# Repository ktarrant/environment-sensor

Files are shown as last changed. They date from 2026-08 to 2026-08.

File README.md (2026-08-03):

# environment-sensor
ESPHome device with ESP32 and BME280 to report Temp/Humidity to Home Assistant

Physically it is two enclosures joined by a 4-pin cable: an MCU end and a sensor
end. The circuit boards are built; the enclosures are in design.

## Layout

| | |
| --- | --- |
| [BOM.md](BOM.md) | The exact parts, with what is verified and what is not |
| [docs/assembly.md](docs/assembly.md) | **The wiring**, and the MCU module as built |
| [docs/measuring.md](docs/measuring.md) | How parts were dimensioned without a caliper |
| [docs/enclosure.md](docs/enclosure.md) | **The enclosure plan** - three units, two shells each |
| [hardware/](hardware/) | OpenSCAD models. `params.scad` holds every dimension |
| [reference/](reference/) | Third-party models kept for cross-checking |
| [images/](images/) | Photos the dimensions were measured from, and renders |

## Build

Needs OpenSCAD (2021.01 tested). `make` writes STLs to `build/` and renders to
`images/renders/`.

```
make                    # everything
make assembly           # just the MCU module
OPENSCAD=/path/to/openscad make
```

## Wiring

Components sit on the face opposite the perfboard silkscreen; the wiring runs on
the silkscreen face so the A..N / 1..20 grid stays readable while soldering.

| # | Signal | Connector | ESP32 hole | ESP32 pin | Wire |
| --- | --- | --- | --- | --- | --- |
| 1 | Power  | C20 (pin 1) | L2  | `3V3` | red |
| 2 | Ground | D20 | B3  | `GND` | black |
| 3 | Clock  | E20 | L15 | `GPIO22 (SCL)` | orange |
| 4 | Data | F20 | L12 | `GPIO21 (SDA)` | blue |

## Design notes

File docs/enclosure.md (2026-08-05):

# Enclosure design plan

Three complete units, one per room. Each unit is **two printed enclosures on a
short pigtail**: an MCU box and a sensor pod. The boards are built and will not
be modified, so every dimension here is a consequence of
[`hardware/params.scad`](../hardware/params.scad), not a free choice.

| Unit | Location | MCU box | Sensor pod |
| --- | --- | --- | --- |
| A | Utility room | screwed to the side of a cabinet | hangs below the box on the pigtail |
| B | Sunroom | discreet, sits at the base of the LEGO orchid's pot | styled as a leaf / unbloomed bud |
| C | Living room | freestanding on a bookshelf | short stub arm off the box, front edge |

## The one constraint that drives everything

**The BME280 cannot share air with the WROOM.** A WROOM-32 with Wi-Fi up
self-heats enough to bias temperature by several degrees, and relative humidity
follows the temperature error. That is why there are two enclosures and not one
box with a divider - a divider still shares the wall, and 3D-printed plastic
conducts well enough to matter at these deltas.

Three rules follow, and they are non-negotiable in every variant:

1. **The pod is a separate volume on a pigtail**, 10-20 cm, per the decision
   made for this design.
2. **The pod is never directly above the MCU box.** Warm air off the box rises;
   put the pod level with it or below, and offset laterally. Unit A hangs the
   pod below the box for exactly this reason.
3. **The pod is vented top and bottom** so it convects, and the BME280 can
   itself sits in the airflow rather than behind a wall.

## Architecture: one family, swappable mounts

Do not design three enclosures. Design **one MCU box and one pod**, each with a
mount interface, and make the three locations three small adapter parts.

```
hardware/
  enclosure_common.scad     shell / lid / boss / vent-slot library, no dimensions of its own
  enclosure_mcu.scad        part = "base" | "lid" | "check"
  enclosure_sensor.scad     part = "base" | "lid" | "check";  style = "plain" | "bud"
  mounts.scad               part = "cabinet" | "shelf" | "orchid"
  fitgauge.scad             printed first, before any enclosure
```

The mount interface is a **dovetail or two-screw pad on the MCU box's back
face**, identical across all three, so a unit can be moved between rooms by
reprinting a 5 g adapter instead of the box. Adding this costs almost nothing
now and is very expensive to retrofit.

Every new dimension goes in `params.scad` with a confidence tag, same as
everything else. `enclosure_common.scad` should hardcode nothing.

## MCU box

### The envelope, from the model

`make assembly` echoes these; they are not estimates.

| | |
| --- | --- |
| Board | 60.00 x 40.00, mounted on its four corner holes, **M2 only** |
| Mount pattern | 56.34 x 36.02 |
| Above the wiring face | **13.20** - the mated connector, not the ESP32 |
| ESP32 stack top | 8.84 - 4.4 mm of headroom under the connector's number |
| Below the wiring face | **4.36** - untrimmed ESP32 header tails, plus the wiring itself |
| Total board-to-board | 17.56 |
| USB-C | -X end, stands **3.31 proud** of the board edge, window at Z = 5.74 to 9.00 above the wiring face |
| ESP32 PCB overhang | 1.56 past the -X board edge, under the USB port |

Interior floor-to-lid is therefore **~13.2 + standoff + margin**, and the
standoff must clear 4.36 of pin tails *plus* the wire runs on that face. Start
at **6.0 mm** standoffs and confirm on the real board - the wiring is hand-laid
and nobody has measured how proud it sits.

### The cable exit is the awkward part

The MCU connector is a **straight header on row 20** - the plug pulls
**straight up**, not sideways, and its face is 13.2 mm above the wiring face.
The cable then has to turn 90 degrees to leave the box. It also sits **7.62 mm
off the board centerline** toward column A (columns C..F), so the exit is *not*
on the box's midline. Two options:

- **Side exit at the +X wall** (recommended). Needs the interior to run to
  roughly 13.2 + one cable bend radius above the board, call it 22-24 mm, with
  a slot in the +X wall at the top. Only 5.87 mm separates the connector center
  from the board edge, so the bend is tight - measure the cable's real minimum
  radius before fixing this.
- **Top exit straight through the lid.** Shortest possible box, but the cable
  stands off the lid, which rules it out for the cabinet mount and looks wrong
  in the sunroom.

Whichever is chosen, **allow `xh_solder_tilt` (5 deg)** at the exit and around
the plug. The built connectors are visibly askew; a slot sized for a
perpendicular plug will bench-test fine and then refuse to close.

USB-C exits the **opposite** (-X) wall, so the two openings never interact.
Cut the USB window oversize - `usb_overhang` at 1.75 is flagged in `params.scad`
as the single highest-risk number in the project - and relieve the outside face
so a chunky USB-C overmold can seat.

### Construction

- Tub + lid. Print the tub open-side-up and the lid face-down: no supports
  anywhere, and the only bridge is the top edge of the USB-C window.
- Vent slots in the walls only, vertical, 1.6 mm (4 nozzle widths) so they
  bridge cleanly. The MCU box vents to keep itself cool; it does **not** need
  to be sensor-grade.
- Do not design a snap-fit lid first - snap fits need a tuned clearance, and
  `clearance` is still `[EST]` at 0.20.

### How it fastens: one screw per corner

The obvious scheme - four screws for the board, four more for the lid - does
not fit. The board is 60 x 40 in an interior that is 63.5 x 40.4, and its
corner holes sit ~1.9 mm from the edges, so the four corners are the *only*
place a post can stand and the board is already using them. Widening the box
to make room for separate lid posts costs ~10 mm across.

So one screw does three jobs:

```
   M2 x 16, head counterbored into the OUTSIDE of the floor
     |  up through the standoff tube        (clearance)
     |  through the perfboard's corner hole (2.2 mm, clearance)
     +->into a post hanging off the lid     (tapped, 6 mm engagement)
```

The board is trapped between the standoff below and the lid post above, and is
**located by the screw shanks** through its 2.2 mm corner holes - not by the
posts, which carry a 2.4 mm clearance bore and so cannot also spigot into a
2.2 mm hole. Nothing else locates it: the cavity walls are deliberately loose
(`enc_board_gap`, 0.4 a side) because a tight cavity would only make the board
hard to drop in without holding it any better.

The heads end up on the outside of the floor, which is where a mount adapter
gets captured later without adding fasteners - at the cost of ~2 mm more screw
length per adapter.

Two consequences:

- The screws are on the bottom, so a wall-mounted unit comes off its keyholes
  before it can be opened. For a sensor that is opened once a year, that is the
  right trade.
- `enc_post_od` is **not a free choice**. At the -X/+Y corner the ESP32's own
  PCB edge is 2.49 mm from the screw axis, so the post is 4.20 mm and clears
  the board it is holding down by **0.39 mm**. Widening it collides. There is
  an `assert()` on exactly this.

## Sensor pod

The board is 13 x 10 and ~2.5 thick, and it is not what sets the size. The
**connector straddles the board** - mated plug 11.6 mm off the trace side,
components and pin tails 3.4 on the other - and the plug's housing is 12.52 mm
wide against a 10 mm board. The pod comes out **27.8 x 21.6 x 21.4** and every
millimetre of that is the connector.

`hardware/enclosure_sensor.scad`, two clamshell halves, built and manifold with
an empty check. Not printed.

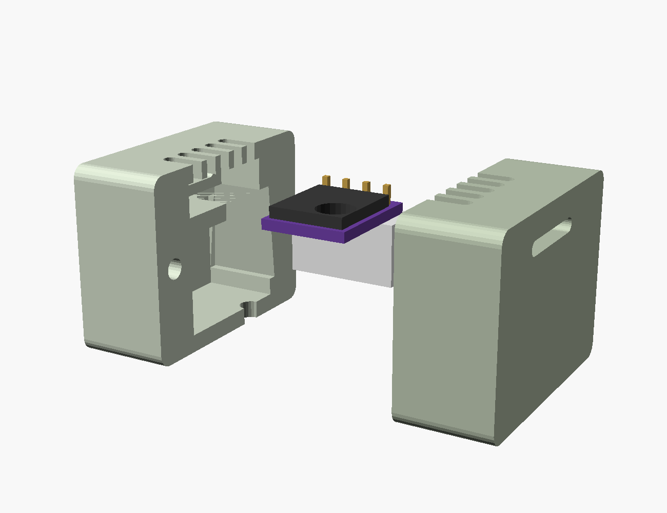
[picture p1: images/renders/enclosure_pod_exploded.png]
pod


### Why a clamshell and not a tub and lid

The interconnect has a housing on **both** ends - both boards carry male
headers - so the cable cannot be threaded through a closed hole, and a hole big
enough to pass a plug is most of the pod's end face. The exit therefore has to
be split between the two halves, which puts the parting plane through the cable
axis. That decision then pays for itself twice over: the halves close sideways
onto the board, so nothing has to be inserted along Z, and the cable gland is
just a half-round in each half that clamps the cable when the screws go in.

### The board is held by the connector, not by a screw

The board's single mounting hole is `[EST]` and its Y sign is
**mirror-ambiguous** - read off a bottom-side photo, so a boss built on it
could land 4 mm out on a 10 mm board. Nothing in this pod uses it, and nothing
here is blocked on that photo.

The connector does the work instead, because it is soldered to the board and
its top face is flush with the board's underside at Z = 0:

- **above Z = 0** the cavity is the *board's* outline only, so shell material
  stands over the connector's flange - it overhangs the board by 1.26 mm each
  side and 0.85 mm past the end - and stops the assembly lifting;
- **below Z = 0** the cavity is the *connector's* outline only, so shell
  material remains under the board out to x = 1.10 and holds it up.

Two boxes, and the board is located in X, Y, Z and rotation with no fastener
through it. It only works because the halves close laterally - a tub and lid
would need insertion clearance in Z and would lose the shoulder. Three
`assert()`s guard it; if any fails the board is loose and the render still
looks perfect.

### The plug pocket leans

`xh_solder_tilt` is finally load-bearing rather than a note. The pocket tapers
**2.03 mm** wider over the plug's depth, so a connector soldered up to 5 degrees
off square still seats. A pocket cut for a perpendicular plug is the classic
way to end up with a pod that will not close, and this one is deep enough
(11.6 mm) for 5 degrees to matter. The taper leans toward the +X screw as it
deepens; there is 1.26 mm left between them, and an assert that says so.

### Venting

- A **grille of 5 slots directly over the sensor**, 48% open, with 2 mm of wall
  between it and the BME280's can.
- One **cross-flow slot** through both side walls, level with the can, so air
  crosses the chamber instead of sitting in it.

### Printing, and the taper that had to go

Each half prints on its **outer face, opening up**. In that orientation every
internal surface is either vertical or a floor with solid material beneath it -
the chamber, the plug pocket and the lower chamber all open upward, the screw
holes run straight up the build direction, and the cable gland is a groove in
the top face. No supports, no bridges.

Getting there cost the pod its taper. The shell used to be narrow over the
sensor and full width over the plug, which thinned the chamber's side walls to
2 mm. The slicer rejected it, and it was right twice over:

- **A clamshell half is a bowl.** Printed rim-down - which is what "on its
  parting face" meant, and it is self-contradictory with "opening up" - its own
  outer wall roofs the cavity as an unsupported ceiling. It has to go outer face
  down. That needs the outer face to be **flat**, and a tapered face is not.
- The taper itself ran at **66 degrees off vertical** in that orientation. An
  earlier note here claimed 25 degrees; that was the same arithmetic with rise
  and run swapped.

The corner rounding was reoriented for the same reason - the rounded edges now
run along the build direction instead of putting a 1.5 mm fillet on the face
that sits on the bed.

The cost is real and worth stating: the chamber's side walls are **5.4 mm
instead of 2.0**, so the cross-flow vent is a duct rather than a slot. The
grille still sits 2 mm off the sensor and is 47% open, and it is the main path.
If the pod lags room air on the bench, enlarge the cross-flow cut before
touching anything else.

The MCU box was checked against the same mistake and is fine: its tub prints
open-side-up and its lid plate-down, both with the cavity opening away from the
bed. The only bridge in the project is the top edge of the USB-C window.

### Still to come for the sunroom

Unit B wants a **double-wall shell** over this one - an outer decorative skin
with an air gap - because sun on a pod reads as a temperature spike that has
nothing to do with the room. That is a miniature Stevenson screen wearing a
flower costume, it wraps the pod rather than replacing it, and it is M5.

## The three variants

### A - utility room, cabinet side

MCU box gets a **flanged back with two keyhole slots** so it drops onto two
pan-head screws already in the cabinet side, then a third screw locks it. Box
vertical, USB-C down so the power lead falls naturally and dust does not settle
in the port. Pod hangs **below** on the pigtail in a plain vented shell, either
free on the cable or clipped to a small bracket 10-15 cm down.

### B - sunroom, LEGO orchid

Two parts, deliberately different in character:

- **MCU box**: low and flat, sitting at the base of the pot, in a colour that
  disappears against it. No LEGO geometry - the orchid model does not offer a
  good attachment, so the box just sits. Cable exits toward the plant.
- **Sensor pod as a leaf or unbloomed bud**: an organic outer shell whose seams
  *are* the vents - louvres reading as leaf veins, or a bud whose petal gaps are
  the airflow path. It hangs or perches among the real LEGO leaves at pot
  height, which is also the height worth measuring in that room.

Print unit B in **PETG, not PLA**. A sunroom behind glass gets near PLA's glass
transition, and a drooping enclosure in a plant is a hard failure to diagnose.

This variant needs the orchid photographed with a scale reference before its
shell is drawn - see below.

### C - living room, bookshelf

Freestanding, so the box carries its own **foot**: stand it on a long edge with
a weighted or wide base so it reads as an object rather than a naked box.
Book-adjacent proportions hide it best. The pod goes on a **short stub arm** off
the front edge so it sits out past the shelf lip and out of the box's thermal
plume, rather than dangling.

## Verifying fit before printing

Two mechanisms, both cheap:

1. **`part = "check"`** in each enclosure file: `intersection()` of the shell
   with the assembly's keepout solids (`esp32_keepout()`,
   `perfboard_keepout()`, `xh_mated_keepout()`). A correct design renders
   **empty**. Anything visible is a collision, found in seconds instead of in
   PLA. This is the natural extension of the `assert()` discipline already in
   the models - asserts catch numbers, this catches geometry.
2. **The fit gauge, printed first** - `hardware/fitgauge.scad`, an 86 x 46 x 3
   plate, `make fitgauge`. It is the idea from the last section of
   [measuring.md](measuring.md), built around the four numbers still guessed:

   | row | what it settles |
   | --- | --- |
   | 5 posts, pilots 1.50-1.90 | `m2_pilot`. Every fastener in the build taps into printed plastic, and this varies by printer and material more than anything else here. Tested at the real 4.2 mm post diameter, where the plastic can actually split |
   | 9 holes, 2.0-3.6 | `cable_od`. The smallest hole the cable passes through **is** its diameter - a measurement, not an estimate, and no caliper needed |
   | 5 windows, -0.30 to +0.30 | the USB-C opening and its overmold relief, in a band milled down to the real 2.0 mm wall |
   | 1 notch with pinch ribs | whether the cable actually snaps into the MCU box's exit and stays there |

   Everything is labelled in hundredths of a millimetre, so "170" is a 1.70 mm
   pilot and "-15" a window 0.15 under nominal. Print it in the material and
   nozzle the enclosures will use - the numbers are only valid for the machine
   that made them.

   Note what is **not** on it: a board-seat pocket. `measuring.md` called for
   one, but neither enclosure locates a board against a cavity wall, so the fit
   it would measure does not exist any more. `enc_board_gap` is 0.4 a side and
   the question is closed.

## Measurements still needed

In priority order. Item 1 blocks printing; 2 blocks unit B's shell only.

1. **The mated plug and its cable**: plug body width and depth, cable outer
   diameter, and how tightly it will actually bend. There is no measured number
   for any of it, and it now sets three things - the MCU box's interior height,
   its cable exit, and the pod's gland, which clamps the cable directly and is
   the one feature that fails outright if `cable_od` is wrong.
2. **The LEGO orchid**, photographed with a 2x4 brick (31.8 mm) in frame:
   pot dimensions, leaf scale, and where a pod could plausibly perch.
3. **The cabinet side** - can it be drilled, or does unit A need adhesive
   mounting instead? Different back geometry either way.
4. **M2 hardware on hand**: every fastener in the project is now an **M2 x 16**,
   four in the MCU box and two in the pod. Confirm that length is available
   before printing anything.

**No longer blocking:** a flat photo of the sensor board was going to be needed
before the pod could be designed, because the mounting hole is `[EST]` and
mirror-ambiguous. The pod does not use that hole, so the photo is now only
worth taking to firm up `bme_pcb_thick` and the outline - neither of which the
design is sensitive to.

## Order of work

| | |
| --- | --- |
| M0 | Take photos 1-3; add the enclosure block to `params.scad`, tagged. **Params done; photos outstanding** |
| M1 | Print the fit gauge (`hardware/fitgauge.scad`, **written**); feed back `m2_pilot`, `cable_od`, `usb_cut_margin` |
| M2 | MCU box v1, plain, no mount. **Drafted - see below.** Fit the real board; iterate the cable exit |
| M3 | Sensor pod, plain vented. **Drafted.** Fit the real sensor board |
| M4 | Three mount adapters; print unit A and unit C |
| M5 | The bud/leaf shell for unit B, in PETG |
| M6 | ESPHome config, then check all three against one reference thermometer in one room before they are dispersed |

M6 is not optional. Three sensors that disagree by a degree are three sensors
you cannot trust; measure the offsets while they are still on the same table.

## The MCU box as drafted

`hardware/enclosure_mcu.scad`, built and manifold, collision check empty. Not
printed yet - every number below is a model, not a measurement.

| | |
| --- | --- |
| Exterior | **67.9 x 44.8 x 27.6 mm** |
| Interior | 63.9 x 40.8 x 23.2 |
| Board sits | 6.0 mm above the inner floor, 17.2 below the rim |
| Fasteners | 4x **M2 x 16**, from below |
| Lid post clearance to the ESP32 | 0.39 mm |
| USB-C shell face | 0.65 mm inside the outer wall - hence the relief pocket |

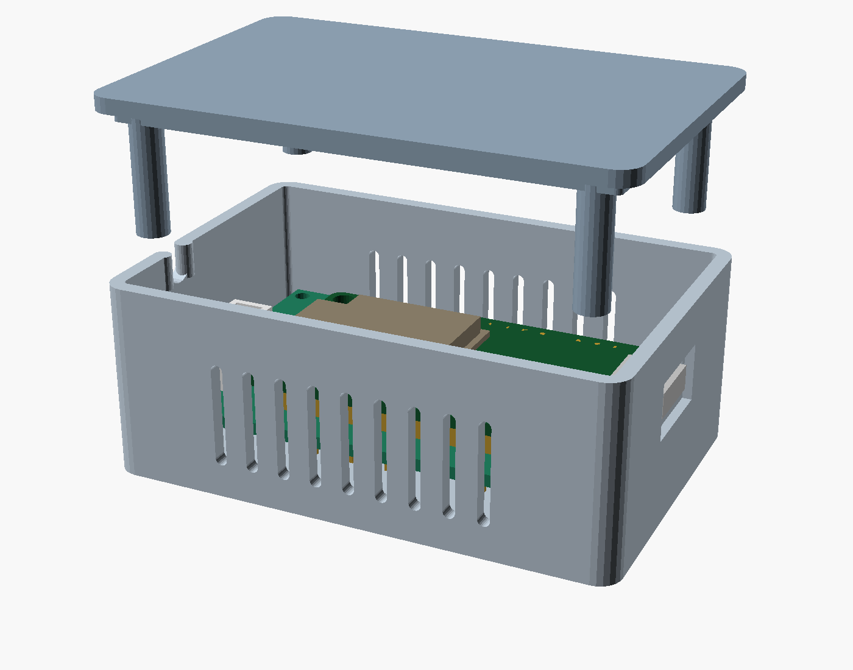
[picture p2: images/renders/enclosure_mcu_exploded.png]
exploded


Two details in the render that look like mistakes and are not: the cable exit
is off the box's midline, because the connector sits on columns C..F rather
than centered; and the box is much deeper above the board than below, because
the mated plug is 13.2 mm tall while the ESP32 stack is only 8.84.

### Still soft in this draft

- `enc_standoff_h = 6.00` clears the 4.36 mm of header tails, but the
  hand-laid wiring on that face has never been measured. First thing to raise
  if the board will not sit flat.
- `enc_cable_head = 4.00` is a stand-in for a bend radius nobody has measured.
- `usb_plug_w/h` - the relief pocket is sized for a guess at the overmold.
- All three belong on the fit gauge.

## What `make check` is and is not good for

It intersects each enclosure with the hardware keepouts and must print
`Current top level object is empty`. Both do. It has now been run in anger on
both ends, and the record is worth keeping honestly:

**What it caught.** Nothing structural in the MCU box - but writing it forced a
correction. The first run reported eight collisions, all of them standoff tops
and post bottoms, i.e. the surfaces that are *supposed* to touch the board. A
keepout that forbids the clamping scheme reports the design as broken by design,
so both checks now exempt exactly the intended bearing surfaces and nothing
else: a ring at each corner hole in the box, the Z = 0 plane in the pod.

At the sensor end it caught a real error, though in the keepout rather than the
pod: `sensor_keepout()` padded the connector's pin tails out by a whole pitch,
making them 10.56 mm wide on a **10 mm board** - impossible, and it would have
flagged any pod built correctly to the board. Sized from the pin row itself now.

**What it missed.** Three real defects, all found by rendering the part and
looking at it:

1. The MCU cable exit was cut to the same height in the lid as in the tub, so
   the channel was open at the top and the cable would lift straight out.
2. The strain-relief ribs sat inside the `difference()`, so the notch erased the
   very bumps meant to pinch the cable.
3. The pod's cross-flow slot originally ran into the chamber ceiling, leaving a
   zero-thickness sliver.

None is a clearance violation, so no keepout could have found any of them. The
check proves parts do not interpenetrate. It says nothing about whether they do
their job.

**One quirk worth knowing.** When a cavity is the board plus *exactly*
`clearance`, every cavity wall is coplanar with a keepout face and CGAL returns
a zero-facet artifact rather than an empty set - which at a glance is
indistinguishable from a real hit. Both enclosures hit this. The right fix
turned out not to be a fudge factor in the check but `enc_board_gap`: the
cavities are now 0.4 a side because **nothing in either enclosure is located by
a cavity wall** - the MCU board by its screws, the sensor board by its
connector - so a tight cavity was only ever going to make a board hard to drop
in. The coplanarity went away as a side effect.

## What the fit gauge returned

First print. Three rows answered, one failed.

| row | result | change |
| --- | --- | --- |
| cable holes | passes 3.40, not 3.20 | `cable_od` **3.00 -> 3.40**. The pigtail is fatter than assumed |
| USB windows | the **smallest** (-0.30) takes the receptacle and the plug with margin | `usb_cut_margin` **0.80 -> 0.50**. `usb_overhang` and the overmold relief are vindicated - that was the flagged risk and it was fine |
| exit notch | the cable slides through the pinch ribs **without being held** | ribs deleted; see below |
| M2 posts | 1.80 split the post, 1.90 accepted the screw | **unresolved** - see below |

### The strain relief did not work

Two bumps the cable was meant to snap past held nothing. That is worse than
having none: it looks like strain relief, and the load goes into the plug.

The MCU box now uses the pod's approach - a **tongue on the lid** that descends
into the notch and squeezes the cable against the notch floor as the four lid
screws come up. Steel pulling plastic onto the cable, not a press fit. The
interference is now `cable_grip = 0.80` in both enclosures, up from 0.40, since
0.40 is precisely the value that was shown not to grip.

### The post row failed rather than answering

An M2's major diameter is 2.00, so a **1.90 pilot leaves 0.05 mm of radial
thread**. It accepted the screw because it is very nearly a clearance hole, and
it will strip on the first or second assembly. It must not be adopted.

The real finding is that the row **conflated two variables**: pilot diameter and
the strength of a thin free-standing column. It can say "a 4.2 mm post will not
take an M2 thread on this printer"; it cannot say what pilot to use in solid
material. That matters because the two threaded joints in this project are not
alike:

- the **pod's** screws tap into **6 mm-thick solid end walls** - no thin wall to
  split, and not the case that failed;
- the **MCU lid's** posts are exactly the case that failed, and the post
  diameter is capped at 4.58 by the ESP32's PCB edge at one corner, so it cannot
  simply be fattened.

**The break settles it: the post sheared off at the plate, hole intact.** That
is a cantilever failing at its root under driver torque - not the thread
splitting the wall. So the pilot is probably not the problem; the gauge drew the
worst possible version of the joint. A 4.20 column meeting a flat face at a
sharp 90 degrees is a stress riser, and in FDM that junction is a joint in the
weakest direction. Two consequences:

- **`enc_fillet = 1.20`** - every post and standoff in both enclosures now
  flares where it meets the plate it stands on. Free to print (the cone is
  wider at the bottom, so it never overhangs) and it is the actual fix for the
  failure that occurred. On the lid posts the flare is 6.6 across, well over
  the 4.58 the tight corner allows, so an assert holds it high above the board.
- **`make fitgauge` now also builds `fitgauge_screws.stl`** - `part="screws"`,
  a 66 x 58 plate. Three rows:

  | row | what it settles |
  | --- | --- |
  | 5 filleted 4.20 posts | the MCU lid's joint, with the fix applied |
  | the same 5 pilots in a solid 8 mm block | the pod's end walls - no column to shear, no thin wall to split. A different joint that the first gauge never tested separately |
  | 4 plug slots, +0 to +1.50 | **the mated plug's outline.** `connector.scad` assumes the plug's footprint matches the header it pushes onto. Nobody has measured it, and the pod's whole pocket is built on that assumption. The smallest slot the plug passes gives the real outline, and the gap from the modelled 12.52 x 5.75 is the `pod_gap` the pocket actually needs |

  One variable per row instead of one row confounding two. Print this before
  either enclosure.

If the filleted posts still shear, the fallback is to move the thread out of the
lid entirely and into a fat, floor-braced boss in the tub, which reverses the
screw direction and puts the heads on the lid.

## What the second gauge returned

### The printer prints small holes undersize

Both gauges picked **1.90** as the best pilot, in a filleted post and in solid
material alike. At face value that is absurd - an M2's major diameter is 2.00,
so a real 1.90 hole leaves 0.05 mm of thread. The consistent reading is that
this printer takes roughly **0.2 mm off a small hole**, so a modelled 1.90 comes
out near 1.70, which is exactly the textbook M2 pilot. It also explains the
first gauge retrospectively: a modelled 1.80 came out near 1.60, which is a lot
of interference, and the post duly split.

`m2_pilot = 1.90` is therefore a **modelled** number carrying a printer
compensation, and it is the only such number in `params.scad`. On a machine that
holds hole size it goes back to ~1.70.

`cable_od` is deliberately **not** corrected the same way, and the distinction is
worth keeping straight:

> A printed feature measured against another printed feature cancels the
> printer's offset. A printed feature measured against a **real object** does
> not. The screw is not printed, so the pilot needs compensating; the gland is
> printed and is derived from a printed hole, so correcting `cable_od` would
> double-count and make the gland too tight by exactly that amount.

### The plug is a centimetre-class error, not a tenth

The slot row was added on a hunch that `connector.scad`'s assumption - that the
mated plug's footprint matches the header it pushes onto - had never been
checked. It was wrong, and not marginally:

| | modelled | measured |
| --- | --- | --- |
| plug outline | 12.52 x 5.75 (the header's) | **14.52 x 7.75** - passes that slot, not 13.52 x 6.75 |

About **1 mm per side bigger** than assumed. `xh_plug_len` / `xh_plug_depth` are
now real parameters, `xh_mated_keepout()` uses them instead of the header's
outline, and the pod's pocket is derived from the plug rather than the header.

The pod grows from 26.8 x 19.6 to **27.8 x 21.6 x 21.4**. Had this gone
undetected, the pod would have printed, looked perfect, passed its collision
check - which was built on the same wrong assumption - and then refused to close
on the one part it exists to hold. The MCU box absorbed the change without
complaint; it had the room.

## What the first printed pod returned

The cable exit was wrong, and wrong in a way none of the modelling caught
because it was built on the wrong mental picture of the part.

`cable_od = 3.40` came from pushing the interconnect through the gauge's hole
row, and that is a fine measurement of a **bundle**. But at the sensor end there
is no bundle: four wires leave the plug spread across the **7.62 mm pin row**,
and the pod asked them to gather into a single 2.6 mm bore within
`pod_cable_room = 2.00` mm. That is a 60 degree convergence, in the 2 mm nearest
a connector, and no wire with any stiffness in it will do that neatly. The bore
also printed slightly flattened, which turned "barely" into "no".

Two changes:

- **`pod_cable_room` 2.00 -> 4.00**, so there is length in which to gather.
- The exit is a **slot, 7.00 x 3.00**, not a bore - and the 7.00 runs **along Y,
  across the parting plane**, so each half's notch goes deeper rather than the
  pair of them running longer along the seam.

That axis took two goes to get right. The first attempt widened the slot **along
the seam**, which is the one direction the wires were never going to use: the
pin row runs along Y, the parting plane bisects it, and the wires fan out two to
a half *perpendicular* to the seam. Widening along X gave them room they did not
want and left the direction they did want at 2.6 mm.

**The exit no longer clamps, and that is the trade.** Y is both the direction the
wires occupy and the direction the halves close on, so an opening wide enough for
them cannot also squeeze them. What keeps a pull off the solder joints is the
plug, at 14.52 across, being far too big to follow the wires through a 7.00
slot - so a hard tug unmates a latched connector rather than lifting a pad.

The pod grows to **27.8 x 21.6 x 23.4**. An `assert()` now ties
`pod_cable_room` to how far the wires actually have to travel, and another
checks the plug cannot pass the slot.

### Third pod: it fits

Closed by hand on the real board and cable. Screws not yet in hand, so this is a
fit result and not yet an assembly result - but a hand-close already retires the
things that would have forced a params change:

- the **plug pocket** takes the mated plug at the corrected 14.52 x 7.75;
- the **parting faces meet** with the board and cable inside, which means
  nothing in the cavity is proud;
- the **cable exit** passes the four wires on the axis they actually run;
- and by implication `bme_conn_inset` (1.50, `[EST]`) leaves enough connector
  flange for the shoulder, since a wrong value there shows up as either a
  rattling board or halves that will not close.

**Screws in, and it holds. The sensor pod is validated.** Every `[EST]` it
depended on has now survived contact with the real parts: the connector-flange
retention, the plug pocket at the corrected outline, the wire-axis exit slot,
and `m2_pilot = 1.90` in a real tapped joint rather than a gauge.

One thing that result does **not** transfer: the pod taps into 6 mm of solid end
wall. The MCU lid's posts are 4.20 mm columns - the same geometry that sheared
on the first gauge. Same pilot, different joint, and `enc_fillet` is a fix that
has still never been driven.

### The same fact at the MCU end

The wires fan across the pin row there too - the connector sits on columns
C..F - and that notch was 5.00 wide against a 7.62 span. Widened to **8.00**,
and the notch floor changed from a half-round to **flat with radiused corners**:
at 8 mm wide a half-round floor curves up steeply at its edges, and it is the
outermost two wires that would have been crushed between that curve and the
clamp tongue.

The MCU end gets to have it both ways, which the pod does not: the wires fan
along Y and the lid's tongue clamps along Z, so widening one costs nothing in
the other.

## Risks

- **Cable bend radius is unmeasured** and sets the MCU box height. The side-exit
  design falls back to the top exit if the cable turns out to be stiff. A 3.40
  cable is stiffer than the 3.00 assumed.
- **`m2_pilot` is `[OPEN]`** - see above. Nothing should be printed for final
  assembly until it is settled.
- **The pod's retention depends on `bme_conn_inset` (1.50, `[EST]`)**, which
  sets how far the connector overhangs the board and therefore how much flange
  the shoulder has to bear on. At 1.06 mm a side there is room to be wrong, but
  not much.
- **Thermal validation is empirical.** The vent design is a reasoned guess. M6
  is what tells you whether the pod actually reads room air, and the fix if it
  does not is a longer pigtail, which is why the connector is there.

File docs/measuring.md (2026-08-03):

# Measuring the boards without calipers

We have no caliper, and a tape measure is worth about ±1 mm — not enough for an
enclosure with a USB-C cutout. Fortunately we don't need one.

## The trick: the header pitch is the ruler

Both boards use **2.54 mm (0.100") header pitch**. That tolerance is held by the
connector manufacturer to well under 0.1 mm, and there are 18 gaps of it across
the ESP32. So instead of measuring the board, we *count pins* and multiply, then
use the same pitch as the scale reference for everything else.

This makes the measurement self-calibrating: any error in camera distance, lens
distortion, or scanner DPI cancels out, because the reference and the subject are
in the same image at the same scale.

## Procedure

1. Lay the board **flat, component side up**, on a plain sheet of white paper.
   Graph paper is a nice sanity check but is not the reference — the pins are.
2. Shoot **straight down**, phone as far back as focus allows, then crop in.
   Distance reduces perspective error; a close-up wide-angle shot will bow the
   edges outward and inflate every dimension.
3. Diffuse light, no flash. A hard shadow along one edge reads as extra board.
4. Take a second shot of the board **on its side**, so the USB-C connector's
   height and how far it overhangs the PCB edge are both visible in profile.
   This is the shot that determines whether the port cutout works.

Four images total: ESP32 top, ESP32 profile, BME280 top, BME280 profile.

A flatbed scanner at 600 dpi beats all of this if one is available — put the board
face down on the glass, leave the lid open, and scan. That is caliper-grade.

## What comes out of it

Derived from pin count alone, no measurement needed:

| Quantity | Derivation | Value |
| --- | --- | --- |
| ESP32 outer pin centers, along length | 14 gaps x 2.54 | **35.56 mm** |
| BME280 header span | depends on pin count, see BOM.md | 5 gaps x 2.54 = 12.7 mm |

This is also how the ESP32 was *identified*: counting 15 pins per row, not 19,
established that it is a 30-pin DevKit V1 rather than the 38-pin board the BOM
originally assumed. The silkscreen label sequence confirmed it independently.

Read off the images, scaled against the pitch:

- PCB length and width, and the pin inset from each edge
- PCB thickness (profile shot; expect ~1.6 mm, the near-universal standard)
- USB-C shell width, height, overhang past the PCB edge, and its offset from the
  board centerline
- Tallest component and its clearance above the PCB (the WROOM-32 can, and the
  electrolytic cap if present)
- BME280: **pin count** — 4 vs 6 tells us which variant shipped, which we still
  need to confirm. See BOM.md.

## What this produced for the ESP32

Worked end to end on images/ESP32_top.jpg. The pitch fit landed on all 30 pins,
giving a scale of **8.66 px/mm** and a board rotation of only 0.17 deg. Measured
outline: 51.4 +/- 0.9 x 28.7 +/- 0.4 mm, which agreed with the DevKit V1 3MF's
51.50 x 28.50 and so validated that model for the rest of the geometry.

Two cautions learned in the process:

- **The vertical axis reads ~1% high.** The board sat left of and below the
  frame center, so it is viewed slightly obliquely and the horizontal pitch
  reference does not transfer cleanly to the vertical. Board width and header
  row spacing both came out high by about that much. Center the part in frame
  next time, or scan it.
- **A downloaded model is not evidence.** The 3MF is excellent in plan but
  flattened in height, and its USB-C overhang (0.70 mm) disagrees with the photo
  (1.75 mm). Where the two conflict on something the enclosure touches, the
  photo of the actual part wins.

## Closing the loop on the first print

Even with good numbers, print a **fit gauge** before printing the enclosure: a
thin plate carrying the USB-C cutout and the board-seat pocket at several
tolerance offsets (-0.3, -0.15, 0, +0.15, +0.3 mm). It takes a few minutes to
print, and it converts a wrong number into a known number by finding which slot
actually fits. That measured offset then feeds back into `params.scad` as the
printer's real-world clearance, and every later part inherits it.

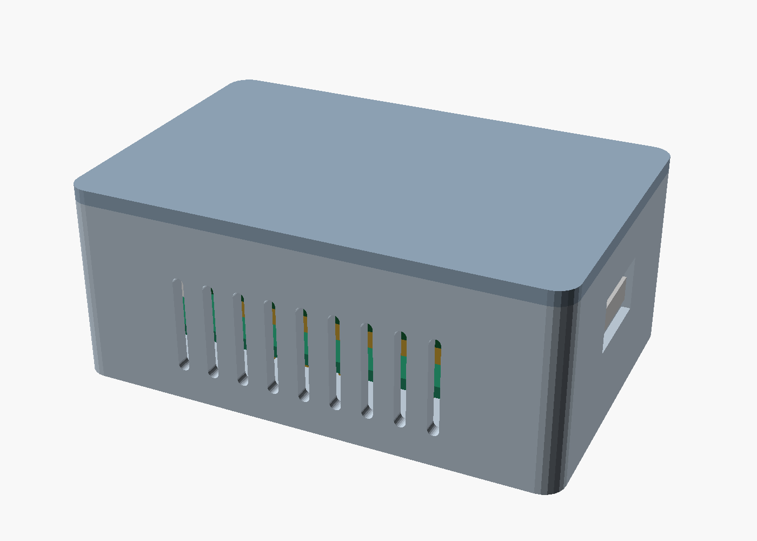
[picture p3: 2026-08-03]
images/renders/enclosure_mcu_iso.png

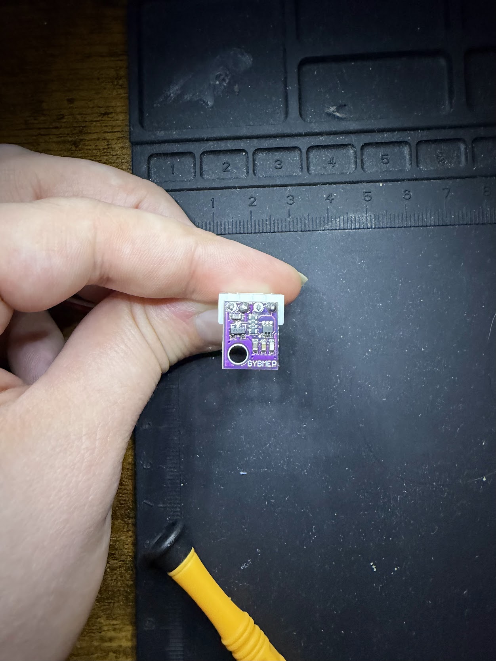
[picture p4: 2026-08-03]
images/sensor_bottom.jpg

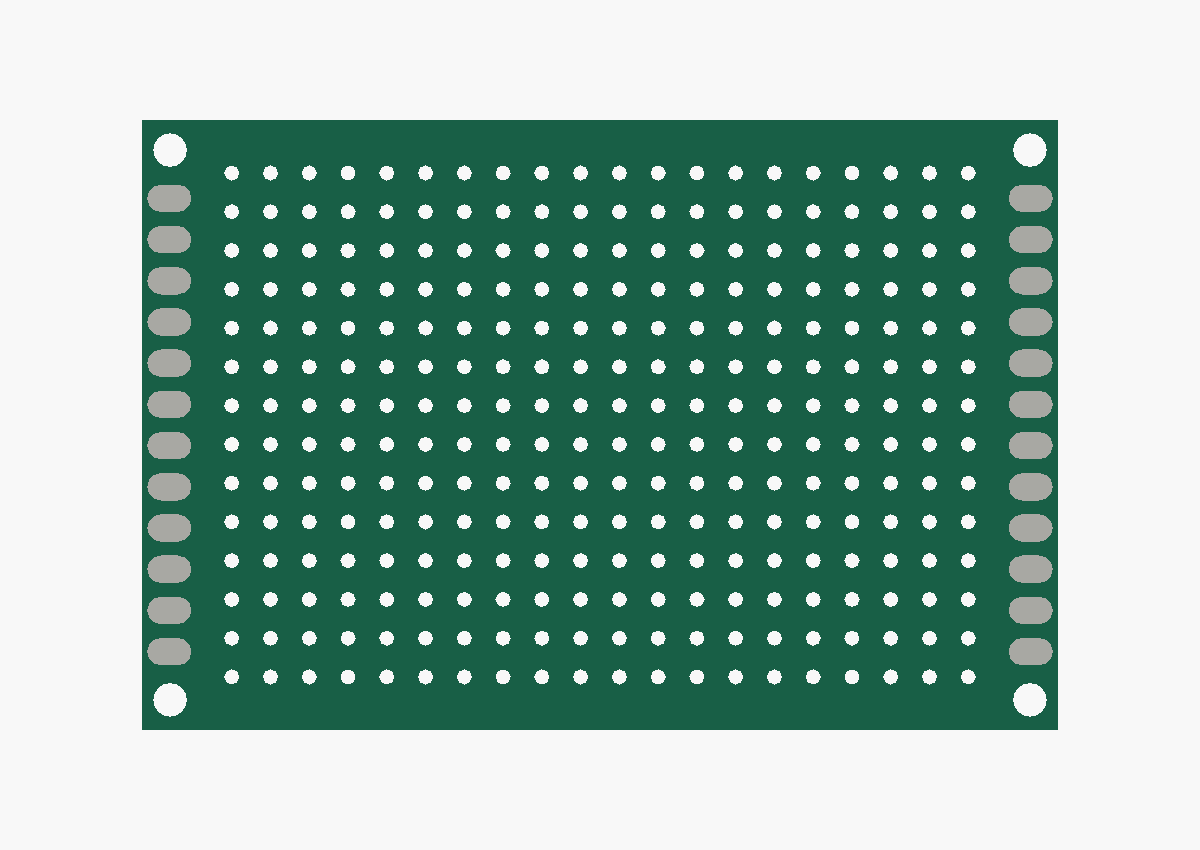
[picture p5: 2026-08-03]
images/renders/perfboard_top.png

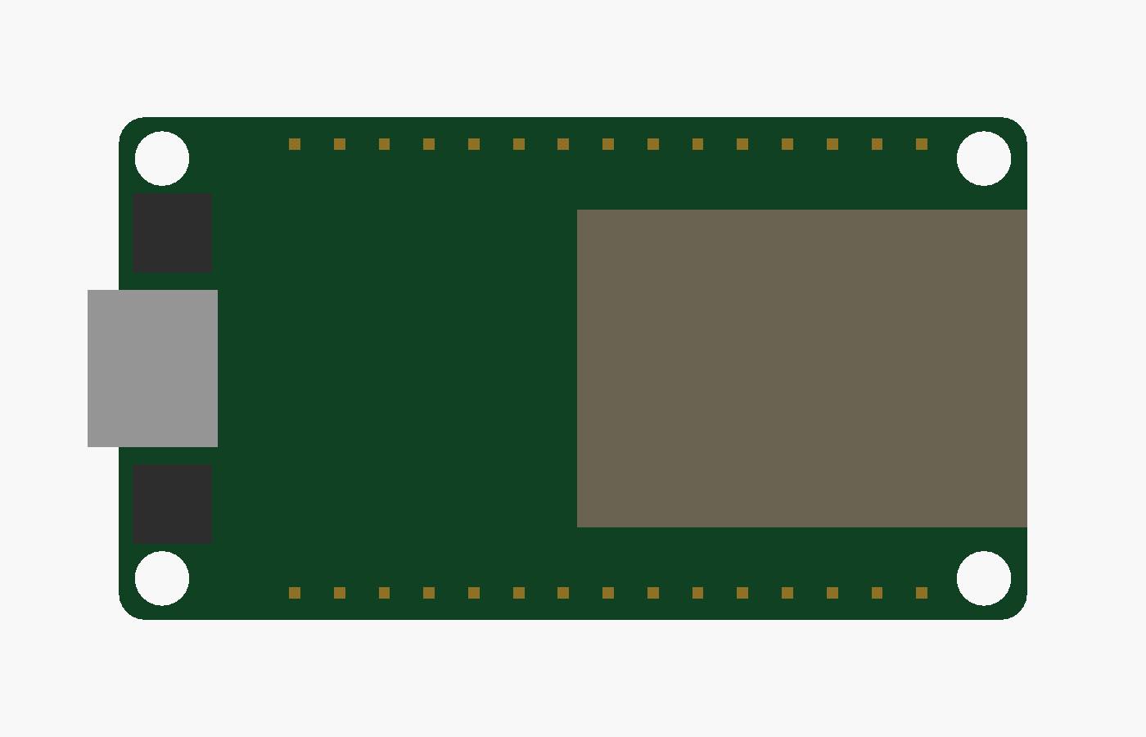
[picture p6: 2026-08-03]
images/renders/esp32_top.png

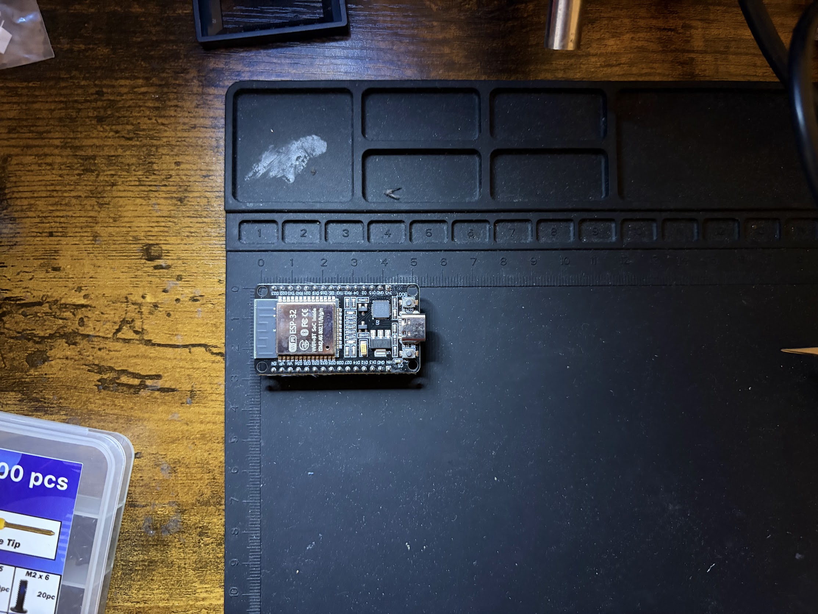
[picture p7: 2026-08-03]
images/ESP32_top.jpg

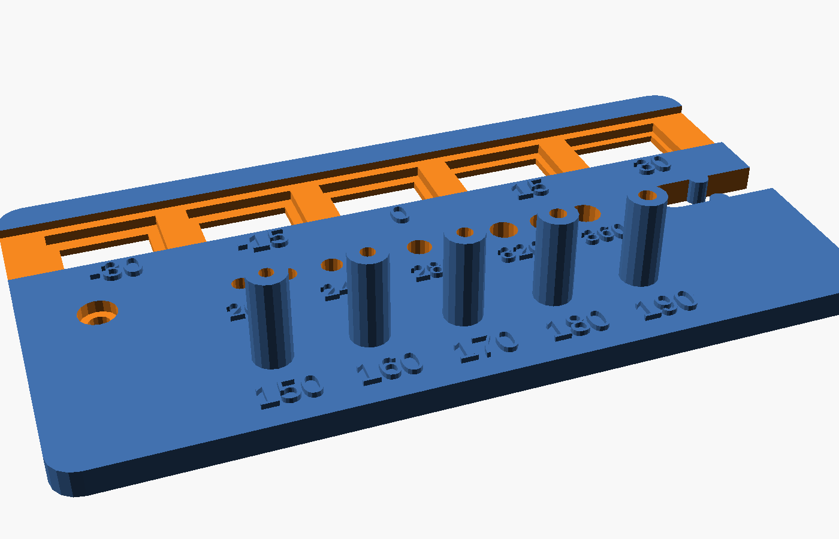
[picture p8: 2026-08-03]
images/renders/fitgauge.png

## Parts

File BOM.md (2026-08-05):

# Bill of Materials

## Exact parts this build used

| Part | Product | Source |
| --- | --- | --- |
| **MCU** | ELEGOO ESP-32 Development Board, 3-pack | Micro Center [#704603](https://www.microcenter.com/product/704603/ESP-32_Development_Board_-_3_Pack), Mfr 50.303.0052 |
| **Sensor** | BME280 5V Sensor Module, 2-pack (GY-BME280) | Amazon [B0DHPCFXCK](https://www.amazon.com/dp/B0DHPCFXCK) |
| **Carrier** | 4 x 6 cm double-sided prototyping board | see below |
| **Interconnect** | 4-pin cable + connectors, MCU end to sensor end | see below |

## MCU - ELEGOO ESP-32 devkit

### It is a 30-pin DevKit V1, not a 38-pin board

This was the first thing the photos settled, and it matters: the two layouts are
different lengths and the 38-pin variants mostly lack mounting holes. Counted
from [images/ESP32_top.jpg](images/ESP32_top.jpg): **15 pins per row, 30 total**,
with the DOIT ESP32 DevKit V1 label sequence:

```
row A:  3V3 GND D15 D2  D4  RX2 TX2 D5  D18 D19 D21 RX0 TX0 D22 D23
row B:  VIN GND D13 D12 D14 D27 D26 D25 D33 D32 D35 D34 VN  VP  EN
```

**Confirmed** (Elegoo's own listing for the same board, [B0D8T53CQ5](https://www.amazon.com/ELEGOO-ESP-WROOM-32-Development-Bluetooth-Microcontroller/dp/B0D8T53CQ5), plus the photos):

- ESP-WROOM-32 module, dual-core 240 MHz, 4 MB flash, ~520 KB SRAM
- Wi-Fi 802.11 b/g/n + Bluetooth 4.2 LE
- **USB-C** connector, **CP2102** USB-UART, EN + BOOT tact switches
- Auto-reset programming circuit - no need to hold BOOT to flash
- **Four corner mounting holes**, ~3.1 mm
- ESPHome: `board: esp32dev`

### Dimensions

No vendor drawing exists - Elegoo publishes none, and Espressif's
[KiCad library](https://github.com/espressif/kicad-libraries) ships STEP for the
WROOM-32 *module* only, not for any devkit carrier board. So the numbers in
[params.scad](hardware/params.scad) come from two independent sources that were
cross-checked against each other:

1. **[reference/esp32_devkitv1.3mf](reference/esp32_devkitv1.3mf)** - a community
   DevKit V1 model. Validated, not trusted blindly: its pin geometry (15/row,
   2.55 pitch, two rows) and outline (51.50 x 28.50) both match the photos.
2. **The photos**, scaled against the 2.54 mm header pitch. Measured
   51.4 +/- 0.9 x 28.7 +/- 0.4 mm.

Where they conflict, see the tags in params.scad. The 3MF is **flattened in
height** and understates the USB-C overhang (0.70 vs a measured 1.75 mm), so
heights and the port cutout come from the photos and datasheets instead.

## Sensor - BME280 breakout

- BME280 (temperature + humidity + pressure), I2C and SPI capable
- I2C address **0x76** with SDO tied low (default), 0x77 with SDO high

### Identified from [images/sensor_bottom.jpg](images/sensor_bottom.jpg)

Purple board, silkscreened **GYBMEP**. It is **not** the 6-pin GY-BME280 this
document originally assumed:

- **4 pins** - VCC / GND / SCL / SDA, **I2C only**. This is why a 4-wire cable
  is sufficient, and it is a neat consistency check on the whole build.
- **Onboard 3.3V LDO** - the SOT-23 marked `662K` is an XC6206. So VCC tolerates
  roughly 3.3-5V, which matches the listing's "5V" claim.
- **One mounting hole.** An earlier note in this file said neither sensor
  variant had mounting holes. That was wrong for the board we actually have.
- **The connector is on the trace side, opposite the components.** Its pins pass
  up through the board and are soldered on the component face - the four dark
  blobs along the top edge of the photo are those solder joints, not the
  connector body. So the sensor end's envelope **straddles** the board rather
  than stacking on one side: ~11.6 mm of mated connector below, ~3.4 mm of
  components and pin ends above, **15 mm across**.
- **13 x 10 mm**, ~2.5 mm thick overall. A vendor reference gives 13 x 10, and
  measuring the photo independently gave 12.3 x 10.4 - two unrelated sources
  within 0.5 mm. (A different listing claimed 9 x 11 x 2; it disagrees with both
  and is disregarded.) Re-shoot flat before designing the sensor enclosure.

### Powering it

The build feeds VCC from the ESP32's **3V3**. That puts the onboard LDO near
dropout, but a BME280 draws microamps, so an XC6206 passes ~3.1-3.2V and the
part runs fine. **If readings ever go erratic, move VCC to VIN/5V first** - that
gives the regulator proper headroom and costs nothing to try.

SCL/SDA go to GPIO22 / GPIO21; see [docs/assembly.md](docs/assembly.md).

### Still worth confirming

**Is it actually a BME280?** These cheap multipacks are notorious for shipping
BMP280 instead - same footprint, no humidity. The `GYBMEP` silkscreen is used
for both. If ESPHome reports pressure and temperature but humidity reads `nan`,
that is what happened.

## Perfboard - 4 x 6 cm prototyping board

The ESP32 is soldered to this, so **the enclosure mounts to the perfboard's four
corner holes, not to the ESP32's**. That makes the perfboard the mechanical
interface, and its corner holes the most important dimensions in the project.

Measured from [images/perfboard_4x6_photo.jpg](images/perfboard_4x6_photo.jpg),
a photo of the actual board at 8.71 px/mm. It carries **silkscreen labels** -
columns A..N, rows 1..20, and "40*60MM" - which settle the grid outright.

- Outline **40 x 60 mm**, 1.6 mm FR-4 (silkscreen confirms)
- **14 x 20** grid of 1.0 mm thru-holes on a 2.54 mm pitch, centered
- Corner mounting holes, **unplated**, on a **36.02 x 56.34 mm** pattern
  (~1.99 and ~1.83 mm in from the respective edges)
- Each 40 mm edge carries **12 elongated SMD pads** - solid tinned copper with
  nothing drilled through - on their **own ~2.70 mm pitch**, not the 2.54 grid

Method check: measuring the round thru-holes the same way returns 1.04 mm
against a 1.0 mm nominal, so these are good to roughly +/-5%.

### The corner holes take M2

**Settled by screw test: M2 passes, M2.5 does not.** So the hole is in
[2.05, 2.50); `params.scad` carries 2.20 as the midpoint.

Worth recording *how* that went, because it is a lesson about the method: my
photo measurement said **1.85 mm**, which the screw test shows was low by at
least 0.2 mm. The radial half-max technique under-reads on an **unplated** hole,
because there is no bright annular ring to bound the edge against - it worked
fine on the plated thru-holes precisely because those have one. A go/no-go check
with a real screw beat careful image analysis here.

### Corrections the real photo forced

The listing image ([perfboard_4x6.png](images/perfboard_4x6.png)) is only
7.0 px/mm and got three things wrong, all now fixed:

| | listing image | actual board |
| --- | --- | --- |
| Grid rows | 21 (inferred) | **20** (silkscreen) |
| Edge features | oval *holes* | **SMD pads**, nothing drilled |
| Edge pad pitch | assumed 2.54 | **~2.70**, its own pitch |

On hole diameter the listing image was the one that got it right: it suggested
2.2-2.5 mm, the photo measurement said 1.85, and the screw test landed on
[2.05, 2.50). A low-resolution source is not wrong about everything, and a
higher-resolution one is not right about everything - which is the argument for
keeping the confidence tags in `params.scad` per-value rather than per-source.

## Connector - "JST-XH style" 2.54 mm, 4-pin

Carries power and I2C between the two enclosures.

**On the pitch:** genuine JST XH (`B4B-XH-A`) is **2.50 mm**, per
[JST's own datasheet](https://www.jst-mfg.com/product/pdf/eng/eXH.pdf). This
build uses a *"JST-XH **style**"* part sold as 2.54 mm, and clone makers do
build true 2.54 versions specifically to drop into 0.1 in perfboard. We model
2.54. Note the two are near-indistinguishable by fit at 4 pins - the pin spans
differ by 0.12 mm total (7.50 vs 7.62), which a 0.95 mm hole absorbs entirely -
so the listing settles this, not how it seats.

Body geometry is from the KiCad model of the genuine `B4B-XH-A`, which agrees
with JST's own footprint outline. Only the pin span is rescaled to 2.54; the
moulding around the pins is a fixed 4.90 mm of plastic either way.

| | |
| --- | --- |
| Body | **12.52 x 5.75 mm** (12.40 at genuine 2.50 pitch) |
| Height above board | **7.00 mm** |
| Pin tails below board | **3.40 mm** |
| Pin post | 0.64 mm square, 0.95 mm recommended drill |
| Shroud offset | 2.35 mm one side of the pin row, 3.40 mm on the latch side |

**Mated height: 11.6 mm** from the board surface to the plug's outer face,
measured off [images/sensor_profile.jpg](images/sensor_profile.jpg) with the
plug face lined up against the mat ruler's zero. This - not the bare 7.00 mm
header - is what sets lid clearance. It does **not** include wire bend radius
beyond the plug; budget that separately at the cable exit.

The connector on that board is soldered slightly askew, so this was measured on
a tilted assembly. A tilt projects *longer*, so 11.6 is more likely a small
over-read than an under-read - the safe direction. Do not shave it.

**Design for the tilt.** Hand-soldered connectors are not reliably square to
their board. Wherever the housing constrains the connector or its cable exit,
allow a few degrees of slop (`xh_solder_tilt`) rather than assuming a
perpendicular plug - otherwise a unit that works on the bench will not close.

## Fasteners

**Every fastener in this project is an M2 x 16.** That is not a coincidence -
it fell out of both enclosures independently and was then kept deliberately, so
there is one line to order and one driver to hold.

| Where | Qty per unit | Size | Threads into |
| --- | --- | --- | --- |
| MCU box, corners | 4 | M2 x 16 | the lid post |
| Sensor pod, ends | 2 | M2 x 16 | the far half's end wall |
| | **6 per unit, 18 for three** | | |

**No nuts, no washers, no heat-set inserts anywhere.** Every thread is formed
directly in printed plastic, which is why `m2_pilot` is the number the fit gauge
worked hardest to settle.

### The screws in hand

**M2 x 16 hex socket head cap, stainless, 0.4 mm pitch** (DIN 912 / ISO 4762 -
head 3.8 mm across, 2.0 mm tall). 100 ordered, 18 needed. **Proven** in the
sensor pod: correct length, head sinks flush in the counterbore, and the thread
holds in a 1.90 pilot tapped straight into printed plastic.

0.4 mm is the standard coarse pitch for M2 and matches the screws the fit gauge
was calibrated with, which is the part that mattered: `m2_pilot = 1.90` is
calibrated to a thread form on a particular printer and does not transfer to a
coarser plastic-forming screw.

**The counterbores were drawn for a 1.4 mm-tall head and these are 2.0.** The
enclosures were changed rather than the screws: `m2_head_h` is 2.20 now, the MCU
box's floor thickened from 2.40 to 3.40 to keep 1.20 mm of material bearing the
head, and the pod's tapped depth went to 9.00 because the same screw now reaches
0.8 mm further in. A proud head would have mattered on the MCU box, whose heads
sit on the face the bookshelf unit stands on.

Consequence: the MCU box is 1 mm taller, **67.9 x 44.8 x 28.6**. An M2 x 16
needs 14.8 mm under the head and gets 7.2 mm of thread engagement.

### Not counted above

- **Mount adapters** (not yet designed). If an adapter is captured by the MCU
  box's own four screws, those grow by its thickness - budget M2 x 20 for the
  units that get one.
- **Wall screws** for the utility-room cabinet mount: whatever suits the
  cabinet, not an M2 anything.

## Enclosure implications

- **Two enclosures**, MCU end and sensor end, joined by a 4-pin cable. Both
  boards are already built and wired; the enclosures are the remaining work.
  The MCU module as built is documented in [docs/assembly.md](docs/assembly.md).
- **Mount through the perfboard's corner holes, with M2.** M2.5 does not pass.
  The ESP32's own mounting holes are unused - it is soldered to the perfboard -
  so the +/-0.6 mm disagreement in the ESP32 hole pattern no longer matters.
- **The mated connector is the tallest thing inside**, at 13.2 mm above the
  wiring face, against 8.84 mm for the ESP32 stack. The lid is set by the
  connector; `xh_mated_h` behind it is now measured at 11.6 mm.
- **USB-C stands 3.31 mm proud of the perfboard end**, and exits the opposite
  end from the 4-pin cable.
- **Allow 4.4 mm under the board** for untrimmed ESP32 header tails, plus the
  wiring itself.
- **The sensor board has a single mounting hole**, so the sensor end needs one
  boss plus something to stop rotation - a slot, a rib, or the connector itself.
- **The sensor cannot share a sealed volume with the ESP32.** A WROOM-32 with
  Wi-Fi active self-heats enough to bias the temperature reading by several
  degrees C, and it will skew relative humidity along with it. The enclosure
  needs the BME280 in a vented chamber thermally separated from the MCU, most
  practically on a short pigtail.

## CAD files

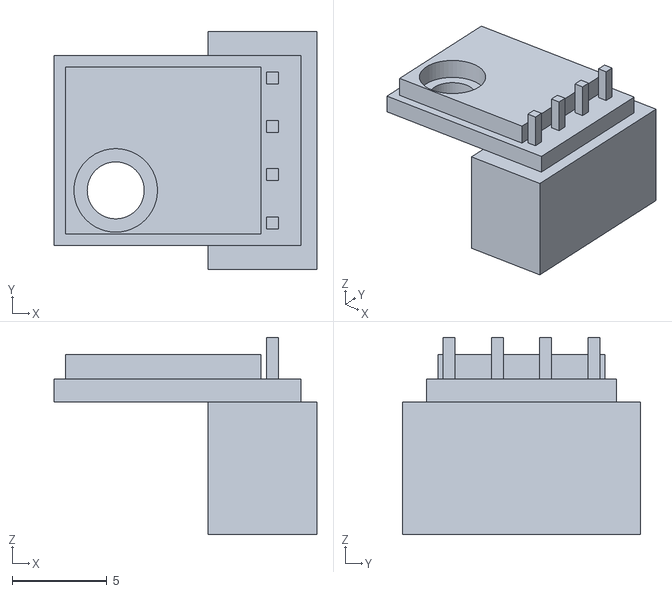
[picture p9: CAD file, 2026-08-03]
build/sensor_assembly.stl
13.8 x 12.5 x 10.4

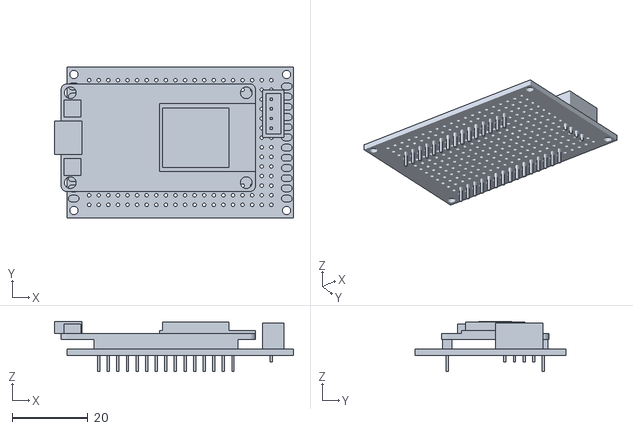
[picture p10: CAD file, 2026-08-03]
build/assembly.stl
63.3 x 40.0 x 13.4

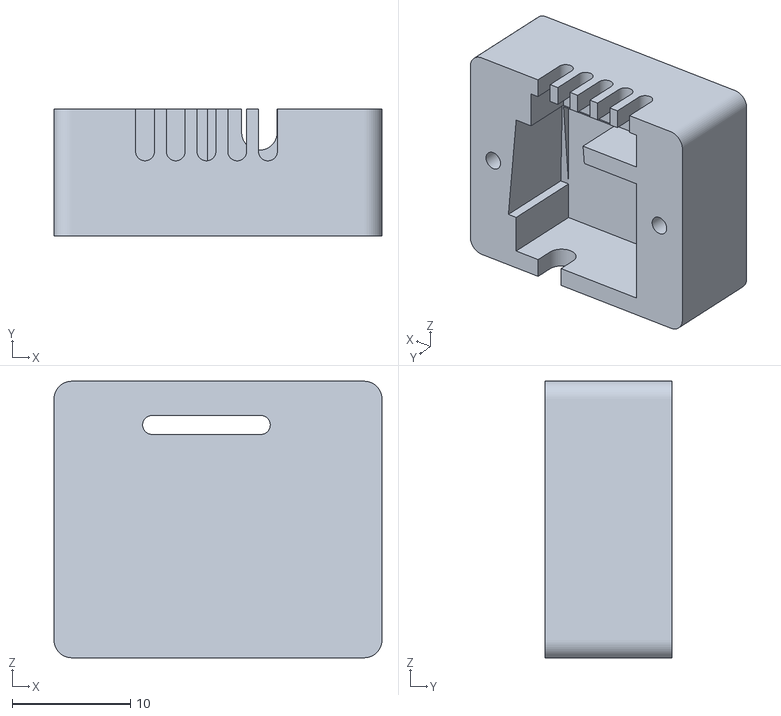
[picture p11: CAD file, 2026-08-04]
build/enclosure_pod_b.stl
27.8 x 10.8 x 23.4

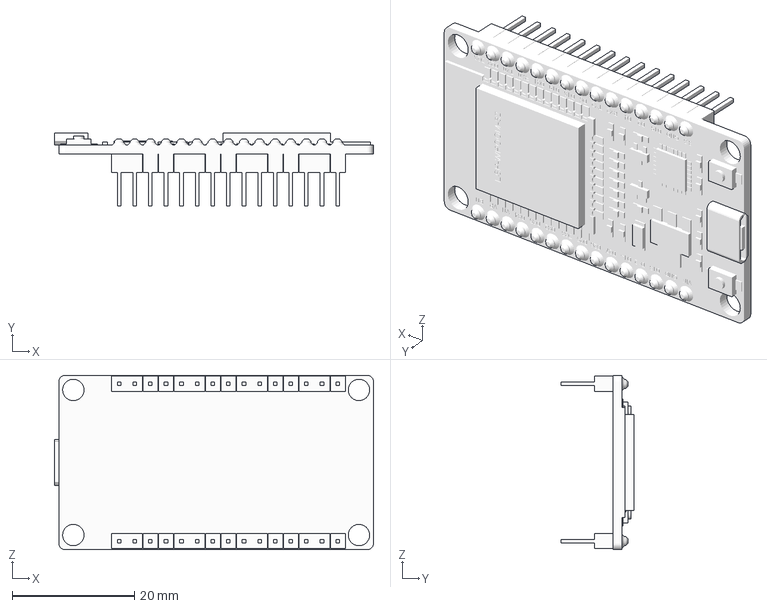
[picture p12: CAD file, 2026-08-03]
reference/esp32_devkitv1.3mf
52.2 x 12.0 x 28.5 mm

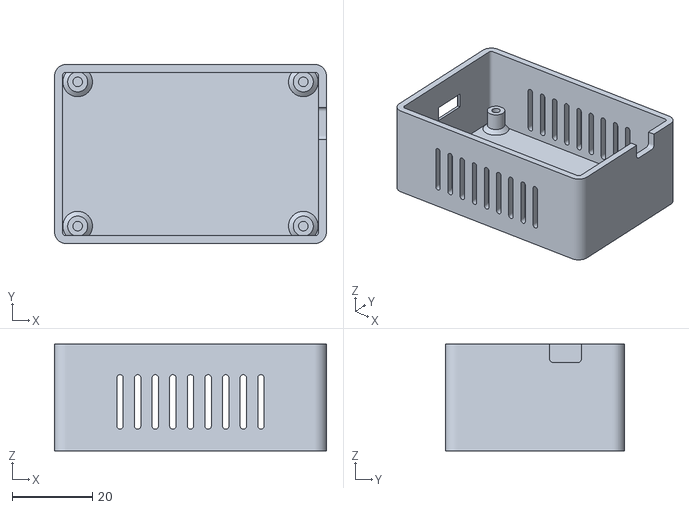
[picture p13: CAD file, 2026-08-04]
build/enclosure_mcu_base.stl
67.9 x 44.8 x 26.6

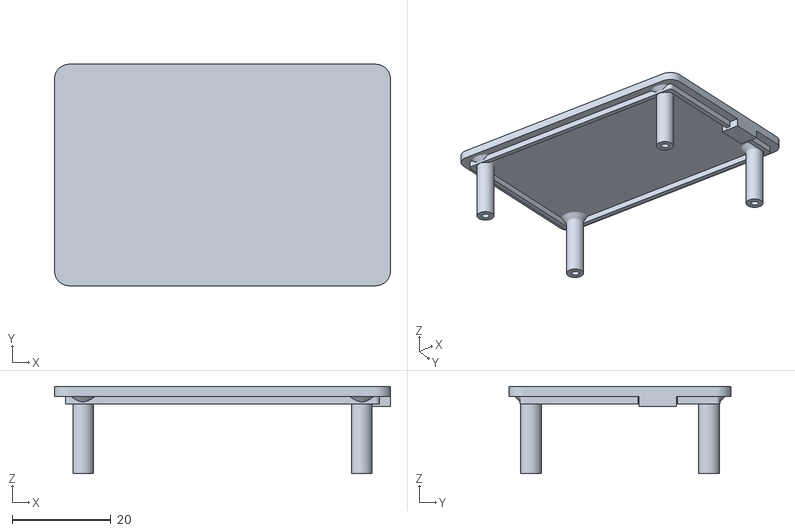
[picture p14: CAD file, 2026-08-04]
build/enclosure_mcu_lid.stl
67.9 x 44.8 x 17.6

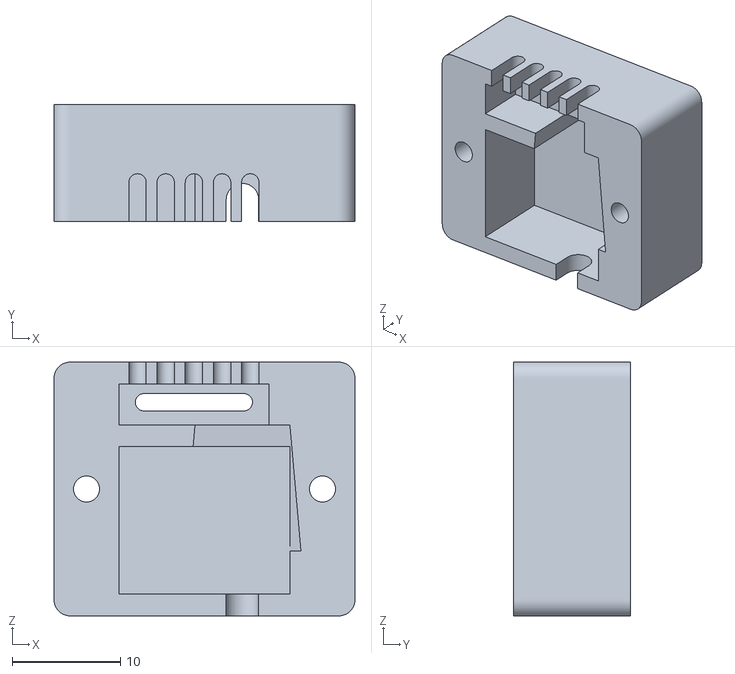
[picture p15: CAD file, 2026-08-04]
build/enclosure_pod_a.stl
27.8 x 10.8 x 23.4

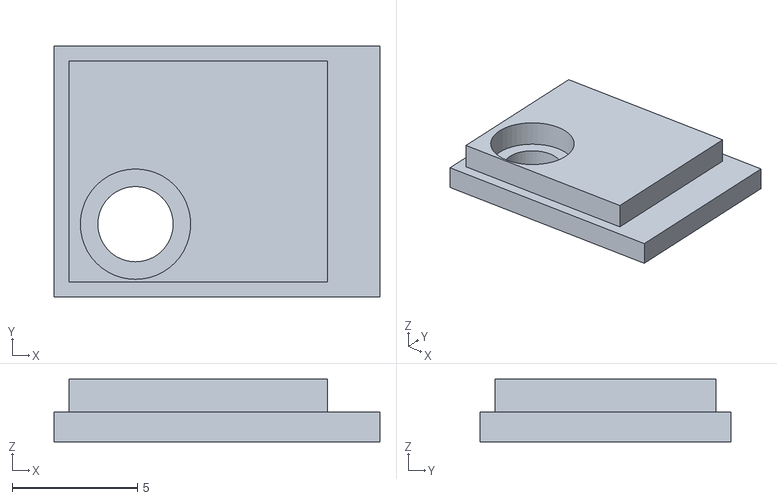
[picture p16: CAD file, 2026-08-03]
build/sensor.stl
13.0 x 10.0 x 2.50

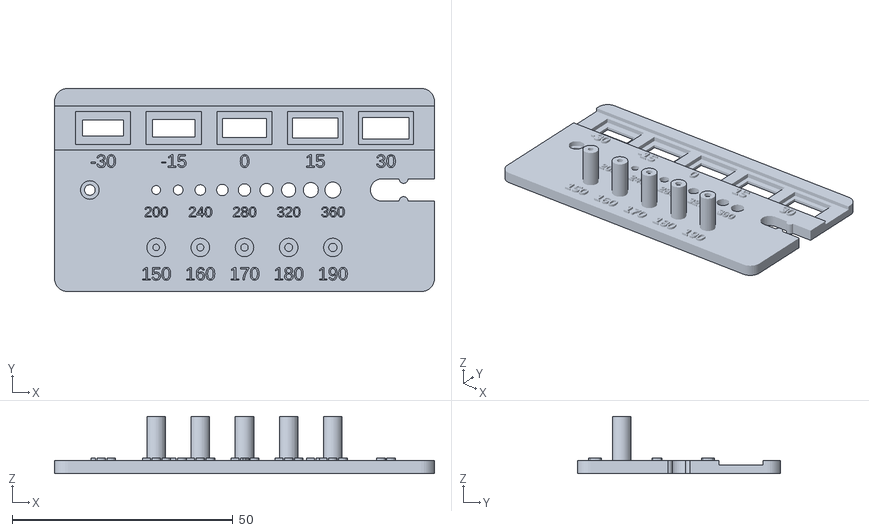
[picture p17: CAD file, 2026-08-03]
build/fitgauge.stl
86.0 x 46.0 x 13.0

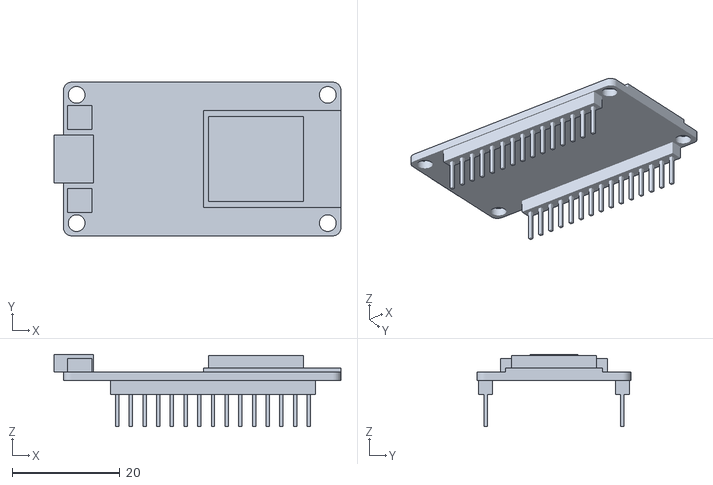
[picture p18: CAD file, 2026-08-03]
build/esp32.stl
53.2 x 28.5 x 13.4

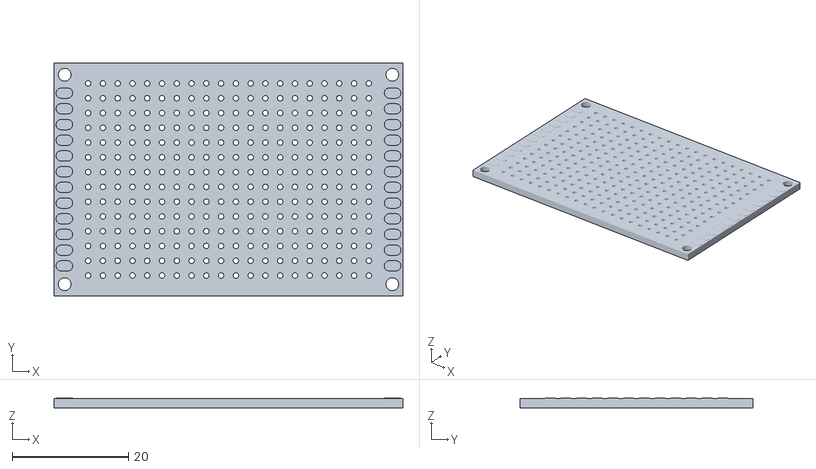
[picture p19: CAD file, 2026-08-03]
build/perfboard.stl
60.0 x 40.0 x 1.70

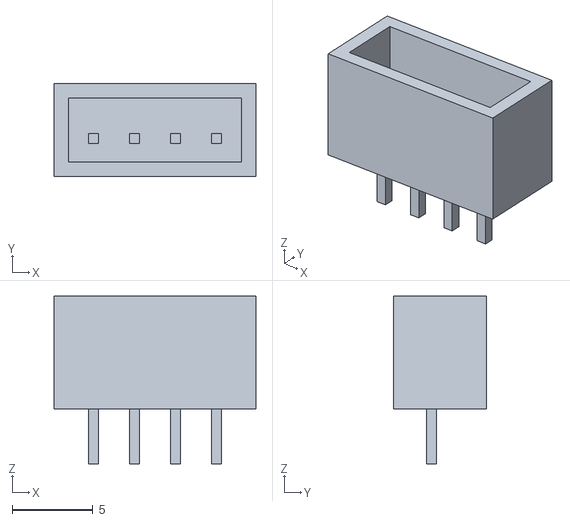
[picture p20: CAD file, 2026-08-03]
build/connector.stl
12.5 x 5.75 x 10.4

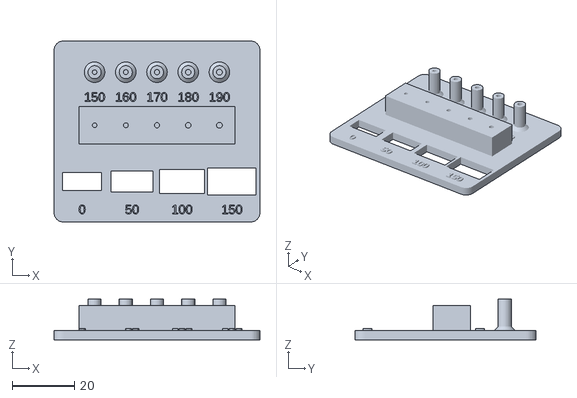
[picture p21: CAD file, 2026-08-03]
build/fitgauge_screws.stl
66.0 x 58.0 x 13.0

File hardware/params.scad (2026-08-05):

// ---------------------------------------------------------------------------
// params.scad - single source of truth for every dimension in this build.
//
// Nothing else in hardware/ hardcodes a number. Correct a value here and
// re-render; everything downstream follows.
//
// Confidence tags:
//   [EXACT]    fixed by a standard, or counted (pin counts).
//   [DERIVED]  computed from an [EXACT] value.
//   [MODEL]    from the DevKit V1 3MF, cross-checked against the photos.
//   [PHOTO]    measured from images/, scaled against the 2.54 mm pin pitch.
//   [DATASHEET] from the Espressif ESP32-WROOM-32 datasheet.
//   [GAUGE]    read off the printed fit gauge, on THIS printer in THIS
//              material. Reprint hardware/fitgauge.scad if either changes.
//   [EST]      placeholder, not yet verified.
//   [OPEN]     sources disagree; see the note. Not enclosure-critical yet.
//
// Coordinate convention for the ESP32 model:
//   origin at the center of the PCB footprint, Z = 0 at the PCB bottom face,
//   +X toward the WROOM/antenna end, -X toward the USB-C end, Z up.
// ---------------------------------------------------------------------------

// --- Universals -------------------------------------------------------------

pitch     = 2.54;   // [EXACT] 0.100" header pitch
pcb_thick = 1.60;   // [EXACT] standard FR-4. 3MF models it as 1.5; photo reads
                    //         ~1.8 edge-on (oblique view). 1.6 is the real part.

// ===========================================================================
// ESP32 - DOIT ESP32 DevKit V1 clone, 30-pin, USB-C
// Sold as ELEGOO ESP-32, Micro Center #704603.
//
// IDENTIFICATION: 30 pins (15 per row), NOT the 38-pin layout. Confirmed twice
// from images/ESP32_top.jpg - pin count and the full silkscreen label sequence
// both match DevKit V1 exactly:
//   row A: 3V3 GND D15 D2 D4 RX2 TX2 D5 D18 D19 D21 RX0 TX0 D22 D23
//   row B: VIN GND D13 D12 D14 D27 D26 D25 D33 D32 D35 D34 VN VP EN
// ===========================================================================

esp_pins_per_row = 15;                              // [EXACT] counted
esp_pin_span     = (esp_pins_per_row-1) * pitch;    // [DERIVED] 35.56 mm

esp_len   = 51.50;  // [MODEL] photo: 51.4 +/- 0.9 -> agrees
esp_width = 28.50;  // [MODEL] photo: 28.7 +/- 0.4 -> agrees
esp_corner_r = 1.5; // [EST]   visible radius, not critical

// Header rows, symmetric about the board centerline.
esp_row_spacing = 25.40;  // [PROVEN] exactly 10 pitches. The board is soldered
                          //   into the perfboard with its two header rows on
                          //   columns B and L, which are 10 * 2.54 apart. A
                          //   part physically seated in a 2.54 grid cannot be
                          //   at any other spacing, so this is now certain.
                          //   (Was [OPEN]: the 3MF read 25.74 and the photo
                          //   25.86. Both were high - the 3MF is loose here and
                          //   the photo's vertical axis carried a ~1% bias.)

// Mounting holes - one near each corner. THIS BOARD HAS THEM; the 38-pin
// variants mostly do not, which is a real advantage for enclosure design.
esp_hole_dx  = 23.30;  // [MODEL] +/- from center, along length
esp_hole_dy  = 11.90;  // [MODEL] +/- from center, across width
esp_hole_dia = 3.10;   // [PHOTO] measured 2.89-3.03 across both axes. The 3MF
                       //   says 3.5 and DevKit V1 is usually quoted at 3.2.
                       //   Treat as "M3 clearance at best, likely tight".
                       //
                       // NOTE on the hole PATTERN: the photo puts the holes at
                       // dx ~23.8, dy ~11.4 against the 3MF's 23.30 / 11.90, so
                       // the two sources agree only to about +/-0.6 mm. Do not
                       // design screw bosses that need tighter alignment than
                       // that - oversize the boss clearance holes, or locate
                       // the board off its outline and treat screws as
                       // secondary retention.

// USB-C receptacle, at the -X end, centered across the width (3MF offset 0.00).
// Shell dims are the standard 16-pin SMD receptacle, NOT taken from the 3MF -
// that model is flattened in height (only 1.8 mm tall vs 3.26 real).
usb_width    = 8.94;   // [EXACT] standard shell; photo reads 8.66 -> agrees
usb_height   = 3.26;   // [EXACT] above PCB top face. The 3MF is flattened to
                       //   1.80 here and must not be used for this.
usb_body_len = 7.35;   // [EXACT] shell length along X; photo reads 7.72
usb_overhang = 1.75;   // [PHOTO] projection past the PCB edge, measured off
                       //   images/ESP32_top.jpg. The 3MF says 0.70 - it is
                       //   WRONG, or at least models a different connector.
                       //   The photo is direct evidence, so it wins. This is
                       //   the single highest-risk number for the port cutout.

// ESP32-WROOM-32 module, at the +X end.
wroom_len     = 25.50;  // [DATASHEET] 18.00 x 25.50 x 3.10
wroom_width   = 18.00;  // [DATASHEET]
wroom_height  = 3.10;   // [DATASHEET] total above the PCB top face
wroom_pcb_h   = 0.80;   // [DATASHEET] module PCB alone (the antenna tail)
wroom_can_len = 17.60;  // [MODEL] the shield can is smaller than the module
wroom_can_w   = 15.74;  // [MODEL]
wroom_x0      = 0.25;   // [MODEL] module starts here, runs to +esp_len/2
wroom_can_x   = 9.95;   // [MODEL] can center along X

// EN and BOOT tact switches, one near each long edge at the USB-C end.
// Positions read off images/ESP32_top.jpg - approximate, but they set the
// height budget at that end of the board so they are worth carrying.
esp_btn_x  = -22.70;  // [PHOTO]
esp_btn_dy =   7.70;  // [PHOTO] +/- from centerline
esp_btn    =   4.50;  // [PHOTO] small SMD tact, body ~4.1 x 3.1 plus solder
                      //   tabs. Not the 6x6 through-hole type.
esp_btn_h  =   2.50;  // [EST]  low-profile SMD tact

// Header assembly below the board.
hdr_plastic_h = 2.54;  // [PHOTO] measured 2.54 exactly - standard part
hdr_below     = 8.50;  // [MODEL] PCB bottom face to pin tips. Photo reads ~9.0
                       //   at an oblique angle; 8.5 is the standard header.
hdr_pin_sq    = 0.64;  // [EXACT] standard square pin
esp_hdr_x_off = 2.00;  // [MODEL] the header rows are NOT centered on the board -
                       //   they sit 2 mm toward the WROOM end, because the
                       //   buttons take the space at the USB-C end.

// Everything else on the top face (CP2102, regulator, EN/BOOT buttons, caps).
// Modeled as a single keep-out slab rather than individual parts - for
// enclosure clearance that is the number that matters.
esp_misc_height = 3.50;  // [EST] keep-out height over the non-WROOM half.
                         //   Driven by the USB-C shell at 3.26; 3.50 leaves a
                         //   little margin for parts not individually modeled.
                         //   Revisit if the lid ends up within ~1 mm of it.

// ===========================================================================
// PERFBOARD - 4 x 6 cm double-sided prototyping board
//
// This is what the enclosure actually mounts to. The ESP32 is soldered to this
// board, so the ESP32's own mounting holes are NOT used - the perfboard's four
// corner holes carry the assembly.
//
// Measured from images/perfboard_4x6_photo.jpg - a photo of the actual board,
// at 8.71 px/mm. It carries silkscreen row/column labels, which settle the grid
// counts outright, and "40*60MM" confirming the outline.
//
// The listing image (images/perfboard_4x6.png) was used first and got several
// things wrong; where they disagree, the photo wins. Method check: measuring
// the round thru-holes the same way returns 1.04 mm against a 1.0 mm nominal,
// so these numbers are good to roughly +/-5%.
// ===========================================================================

pb_len   = 60.00;  // [EXACT] stated on the listing image, confirmed by aspect
pb_width = 40.00;  // [EXACT]
pb_thick =  1.60;  // [EXACT] standard FR-4

pb_pitch = 2.54;   // [EXACT] silkscreen grid; measured 2.549
pb_cols  = 14;     // [EXACT] silkscreen labels A..N. Span 13*2.54 = 33.02 mm
pb_rows  = 20;     // [EXACT] silkscreen labels 1..20. Span 19*2.54 = 48.26 mm
                   //   Both grids are centered on the board (measured margins
                   //   3.70/3.12 and 5.80/5.17 vs 3.49 and 5.87 nominal).
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

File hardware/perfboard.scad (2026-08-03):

// ---------------------------------------------------------------------------
// perfboard.scad - 4 x 6 cm prototyping board that carries the ESP32.
//
// The enclosure mounts to THIS board's four corner holes, not to the ESP32's.
// `pb_mount_positions()` is therefore the interface the housing is built
// around; the hole grid is cosmetic and can be switched off to render faster.
//
// Origin: center of the board, Z = 0 at the bottom face.
// +X is the long (60 mm) axis, matching the ESP32 model's convention, so the
// two boards' long axes line up when assembled.
//
// Render:  openscad -o build/perfboard.stl hardware/perfboard.scad
// ---------------------------------------------------------------------------

include <params.scad>

show_grid = true;   // false gives a fast preview - the grid is ~320 holes
$fn = $preview ? 16 : 32;

// --- silkscreen grid addressing --------------------------------------------
//
// The board is labeled with columns A..N and rows 1..20. Those labels are on
// the WIRING face; components mount on the opposite face. The mapping below is
// oriented so that, viewed from the component side (+Z) with row 20 up, column
// A is to the left - which is how images/esp32_assembled_top.jpg reads.
//
// Use pb_hole("L", 2) rather than raw coordinates, so wiring notes transcribe
// directly into geometry and stay checkable against the build.

function pb_row_x(n) = -(pb_rows-1)*pb_pitch/2 + (n-1)*pb_pitch;   // n = 1..20
function pb_col_i(L) = search(L, "ABCDEFGHIJKLMN")[0];             // "A".."N"
function pb_col_y(L) =  (pb_cols-1)*pb_pitch/2 - pb_col_i(L)*pb_pitch;
function pb_hole(L, n) = [pb_row_x(n), pb_col_y(L)];

// Corner hole centers. Enclosure code should call this rather than re-deriving
// the pattern, so that a corrected inset propagates everywhere at once.
function pb_mount_positions() =
    [ for (sx = [-1,1], sy = [-1,1]) [sx*pb_mount_dx, sy*pb_mount_dy] ];

// Grid runs pb_rows along the 60 mm axis (X) and pb_cols along the 40 mm axis.
// $fn is pinned low here on purpose: this is ~320 holes of 1 mm, and at the
// default facet count CGAL takes over two minutes to difference them. At $fn=8
// it is a few seconds and looks identical at any sane render scale.
module pb_grid_holes() {
    for (r = [0 : pb_rows-1], c = [0 : pb_cols-1])
        translate([-(pb_rows-1)*pb_pitch/2 + r*pb_pitch,
                   -(pb_cols-1)*pb_pitch/2 + c*pb_pitch, -1])
            cylinder(h = pb_thick + 2, d = pb_hole_dia, $fn = 8);
}

module pb_mount_holes() {
    for (p = pb_mount_positions())
        translate([p[0], p[1], -1])
            cylinder(h = pb_thick + 2, d = pb_mount_dia);
}

// Oval edge pads. These are SURFACE PADS, not holes - solid tinned copper with
// nothing drilled through - so they are added on top of the board, never
// subtracted. They also run on their own pitch rather than the 2.54 grid.
module pb_edge_pads_solid() {
    for (sx = [-1,1], k = [0 : pb_edge_pads-1])
        translate([sx*pb_edge_pad_x,
                   -(pb_edge_pads-1)*pb_edge_pad_pitch/2 + k*pb_edge_pad_pitch,
                   pb_thick])
            hull() for (s = [-1,1])
                translate([s*(pb_edge_pad_l - pb_edge_pad_w)/2, 0, 0])
                    cylinder(h = pb_edge_pad_h, d = pb_edge_pad_w, $fn = 12);
}

module perfboard() {
    color("#1f7a5a")
        difference() {
            translate([0, 0, pb_thick/2])
                cube([pb_len, pb_width, pb_thick], center = true);
            pb_mount_holes();
            if (show_grid) pb_grid_holes();
        }
    if (show_grid) color("#d8d8d2") pb_edge_pads_solid();
}

// Clearance solid for enclosure boolean ops.
module perfboard_keepout(gap = clearance) {
    translate([0, 0, pb_thick/2])
        cube([pb_len + 2*gap, pb_width + 2*gap, pb_thick + 2*gap], center = true);
}

// --- guards -----------------------------------------------------------------

assert((pb_rows-1)*pb_pitch < pb_len,  "row grid does not fit the board length");
assert((pb_cols-1)*pb_pitch < pb_width,"column grid does not fit the board width");
assert(pb_mount_dx + pb_mount_dia/2 < pb_len/2,   "mount hole breaks the end edge");
assert(pb_mount_dy + pb_mount_dia/2 < pb_width/2, "mount hole breaks the side edge");

// The corner holes must clear the round grid. Getting this wrong merged them
// into keyholes, which is how the bad row count was caught in the first place.
assert(norm([pb_mount_dx - (pb_rows-1)*pb_pitch/2,
             pb_mount_dy - (pb_cols-1)*pb_pitch/2]) > (pb_mount_dia + pb_hole_dia)/2,
       "corner mounting hole collides with the round hole grid");
// ...and the SMD pad row must clear them too (pads run on their own pitch).
assert(pb_mount_dy - (pb_edge_pads-1)*pb_edge_pad_pitch/2
         > (pb_mount_dia + pb_edge_pad_w)/2,
       "corner mounting hole collides with the SMD edge pads");
assert(pb_edge_pad_x + pb_edge_pad_l/2 < pb_len/2,
       "SMD edge pads run off the end of the board");

perfboard();

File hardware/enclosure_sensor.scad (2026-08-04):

// ---------------------------------------------------------------------------
// enclosure_sensor.scad - sensor pod: two clamshell halves.  FIRST DRAFT.
//
// Origin and axes are sensor.scad's:
//   center of the PCB footprint, Z = 0 at the TRACE face,
//   +X toward the connector edge, connector pins running along Y.
// The components are on +Z and the mated plug hangs off -Z, so the pod is
// deep on the -Z side. IN USE the pod hangs with -Z UP: the cable leaves the
// top, the sensor faces down out of the grille, and the pod sits level with or
// below the MCU box, never above it.
//
// WHY A CLAMSHELL, NOT A TUB AND LID
//
// The interconnect has a housing on BOTH ends - both boards carry male headers
// - so the cable cannot be threaded through a closed hole. The exit has to be
// split, which puts the parting plane through the cable axis (y = 0). Once it
// is there, the two halves close sideways onto the board and nothing needs to
// be inserted along Z.
//
// HOW THE BOARD IS HELD - no screw touches it
//
// The board's one mounting hole is [EST] and its Y sign is mirror-ambiguous,
// so a boss built on it could land 4 mm out on a 10 mm board. Nothing here
// uses it. Instead the connector does the work, because it is soldered to the
// board and its top face is flush with the board's underside at Z = 0:
//
//   above Z=0  the cavity is the BOARD's outline only, so shell material
//              stands over the connector's flange - it overhangs the board by
//              1.26 mm each side and 0.85 mm past the end - and stops the
//              assembly lifting.
//   below Z=0  the cavity is the CONNECTOR's outline only, so shell material
//              remains under the board out to x = 1.10 and holds it up.
//
// That locks X, Y, Z and rotation with two boxes and no fasteners through the
// board. It works only because the halves close laterally; a tub and lid would
// need clearance in Z for insertion and would lose the shoulder.
//
// The plug pocket TAPERS by xh_solder_tilt over the plug's depth. The built
// connectors are visibly askew and a pocket cut for a perpendicular plug is
// the classic way to end up with a pod that will not close.
//
// PRINT: each half on its OUTER FACE, opening up. That is the whole reason the
// pod is a straight box rather than the tapered one it started as - see
// pod_shell(). In this orientation the build direction is Y, so every internal
// face is either vertical or a floor with solid beneath it: the chamber, the
// plug pocket and the lower chamber all open upward, the screw holes run
// straight up, and the cable gland is a groove in the top face. No supports,
// no bridges.
//
// Do NOT print it rim-down. A clamshell half is a bowl, and rim-down puts its
// own outer wall over the cavity as an unsupported ceiling.
//
// Render:
//   openscad -o build/pod_a.stl -D 'part="a"' hardware/enclosure_sensor.scad
//   openscad -o build/pod_b.stl -D 'part="b"' hardware/enclosure_sensor.scad
//   part="check" must render EMPTY.
// ---------------------------------------------------------------------------

include <params.scad>
use <enclosure_common.scad>
use <connector.scad>
use <sensor.scad>

part = "a";     // "a" | "b" | "check" | "assembled" | "exploded"
$fn = $preview ? 24 : 48;

// --- the cavity, derived from the board -------------------------------------

// The pocket is sized to the mated PLUG, not to the header - the fit gauge put
// the plug about 1 mm per side outside the header's outline, and the pocket is
// what has to swallow it.
in_x0     = -(bme_len/2 + enc_board_gap);    // board end
in_x1     = max(bme_conn_x1(), bme_plug_x1()) + pod_gap;
pocket_x0 = min(bme_conn_x0(), bme_plug_x0()) - pod_gap;

in_y_board = bme_width/2   + enc_board_gap;  // sensor chamber
in_y_conn  = xh_plug_len/2 + pod_gap;        // plug, at the board
tilt       = xh_mated_h * tan(xh_solder_tilt);
in_y_max   = in_y_conn + tilt;               // ...and at the plug's face

in_z1  = bme_above() + enc_board_gap;        // top of the sensor chamber
z_plug = -xh_mated_h;                        // the mated plug's outer face
in_z0  = z_plug - pod_cable_room;

// End walls carry the two screws, which run along Y through the parting plane.
screw_x0 = in_x0 - pod_screw_wall;
screw_x1 = in_x1 + pod_screw_wall;
screw_z  = (in_z1 + in_z0)/2;

out_x0     = screw_x0 - pod_screw_wall;
out_x1     = screw_x1 + pod_screw_wall;
out_y      = in_y_max + pod_wall;            // set by the plug at full tilt
out_z1     = in_z1 + pod_wall;
out_z0     = in_z0 - pod_wall;

cable_x  = (bme_conn_x0() + bme_conn_x1())/2;
grille_l = 2*in_y_board - 2.0;
// Cross-flow slot, placed off the SENSOR rather than off the ceiling: it wants
// to be level with the BME280's can, and hanging it off in_z1 walked it up into
// the chamber roof and left a 0.6 mm sliver there when the chamber grew.
cross_z  = bme_pcb_thick + pod_vent_w/2 + 0.10;

// The pocket leans out as it deepens. Where it ends up matters twice: against
// the side wall, and against the +X screw.
function pocket_x1_at(z) = in_x1 + abs(min(z, 0)) * tan(xh_solder_tilt);

// --- helpers ----------------------------------------------------------------

module box3(x0, x1, yh, z0, z1) {
    translate([x0, -yh, z0]) cube([x1 - x0, 2*yh, z1 - z0]);
}

// Cylinder running along +Y from the origin.
module ycyl(h, d) { rotate([-90, 0, 0]) cylinder(h = h, d = d); }

// --- shell ------------------------------------------------------------------

// A straight box, and it has to stay one. This was tapered - narrow over the
// sensor, full width over the plug - to thin the chamber's side walls. The
// taper made the part unprintable and the slicer caught it:
//
//   A clamshell half is a bowl. Printed rim-down its cavity is roofed by its
//   own outer wall, which is a ceiling over a void; so it must be printed
//   OUTER FACE DOWN, opening up. That needs the outer face to be flat - and a
//   tapered face is not. Worse, the taper itself ran at 66 degrees off vertical
//   in that orientation. (An earlier comment here claimed 25 degrees. That was
//   the same arithmetic with rise and run swapped.)
//
// The cost is real: the chamber's side walls are 5.4 mm instead of 2.0, so the
// cross-flow vent is a duct rather than a slot. The grille sits 2 mm off the
// sensor and does the work; see the note in pod_vents_cut().
// The rounded edges run along Y, not along Z. Same reason: Y is the build
// direction, so edges parallel to it are vertical and cost nothing, while
// rounding the other way would have put a 1.5 mm fillet on the face that sits
// on the bed - a small overhang, but an avoidable one.
module pod_shell() {
    cx = (out_x0 + out_x1)/2;
    lx = out_x1 - out_x0;
    cz = (out_z0 + out_z1)/2;
    hz = out_z1 - out_z0;
    hull() for (sx = [-1,1], sz = [-1,1])
        translate([cx + sx*(lx/2 - pod_r), -out_y, cz + sz*(hz/2 - pod_r)])
            rotate([-90, 0, 0]) cylinder(h = 2*out_y, r = pod_r);
}

module pod_cavity() {
    // sensor chamber: the BOARD's outline, nothing wider
    box3(in_x0, -in_x0, in_y_board, 0, in_z1);
    // connector and plug: the CONNECTOR's outline, tapering out for solder tilt
    hull() {
        box3(pocket_x0, in_x1, in_y_conn, -0.01, 0);
        box3(pocket_x0 - tilt, in_x1 + tilt, in_y_max, z_plug, z_plug + 0.01);
    }
    // and below the ledge it is all one chamber, so the pod is not a solid
    // block of plastic with a hole in it
    box3(in_x0, in_x1, in_y_max, in_z0, -pod_ledge_t);
}

// Grille straight over the sensor, plus one cross-flow cut through both side
// walls. The grille is 2 mm from the BME280's can and is the main path - it is
// 47% open directly over the sensor. The cross-flow cut gives convection
// somewhere to go; with the taper gone it passes through 5.4 mm of wall, so it
// is a duct rather than a slot. If bench testing shows the pod lagging room
// air, enlarge this before touching anything else.
module pod_vents_cut() {
    for (i = [0 : pod_vents-1])
        translate([-(pod_vents-1)*pod_vent_pitch/2 + i*pod_vent_pitch,
                   0, in_z1 - 0.1])
            rotate([0, 0, 90]) pill(grille_l, pod_vent_w,
                                    (out_z1 - in_z1) + 0.2);
    // through both faces in one cut, high in the chamber where the wall is
    // thinnest
    translate([0, -20, cross_z]) rotate([-90, 0, 0])
        pill(2*in_y_board, pod_vent_w, 40);
}
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

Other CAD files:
hardware/sensor.scad
hardware/assembly.scad
hardware/connector.scad
hardware/enclosure_common.scad
hardware/enclosure_mcu.scad
hardware/esp32.scad
hardware/fitgauge.scad

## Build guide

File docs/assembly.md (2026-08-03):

# MCU module - as built

The ESP32 and the 4-pin connector are soldered to a 4x6 cm perfboard. Both
units of this design are already built; what follows documents them.

## Which face is which

Components are on the face **opposite** the silkscreen. The wiring runs on the
silkscreen face, so the A..N / 1..20 grid labels stay readable while soldering.

In the model, the component face is +Z and the wiring face is Z = 0.

## Wiring

| # | Signal | Connector | ESP32 hole | ESP32 pin | Wire |
| --- | --- | --- | --- | --- | --- |
| 1 | Power  | C20 (pin 1) | L2  | `3V3` | red |
| 2 | Ground | D20 | B3  | `GND` | black |
| 3 | Clock  | E20 | L15 | `GPIO22 (SCL)` | orange |
| 4 | Data | F20 | L12 | `GPIO21 (SDA)` | blue |

## The wiring is the placement

[assembly.scad](../hardware/assembly.scad) does not eyeball the layout from the
photos. It solves the ESP32's position from wire 1 alone, then **asserts** that
wires 2, 3 and 4 land on their own holes. Three independent checks on one
placement - if any dimension feeding into it were wrong, the render would fail
rather than quietly drift.

The photos are used only to confirm the result and to fix handedness (which
header row faces which way).

A useful by-product: the ESP32's two header rows land on columns **B and L**,
exactly **10 pitches = 25.40 mm** apart. A part physically seated in a 2.54 mm
grid cannot be at any other spacing, so this settles a row-spacing figure that
neither the 3MF (25.74) nor direct photo measurement (25.86) had pinned down.

## Resulting geometry

Origin at the perfboard center, Z = 0 at the wiring face, +X toward row 20
(the connector end), +Y toward column A.

| | |
| --- | --- |
| ESP32 offset from board center | (-5.81, +1.27) mm |
| ESP32 PCB bottom | 4.14 mm (1.6 board + 2.54 header plastic) |
| ESP32 stack top (WROOM) | 8.84 mm |
| **Connector, mated** | **13.20 mm - this sets the lid height** |
| Below the wiring face | 4.36 mm of untrimmed ESP32 header tail |
| Total envelope | 17.56 mm |

Two consequences worth carrying into the enclosure:

- **The USB-C port stands 3.31 mm proud of the perfboard's end.** The ESP32
  itself overhangs that end by 1.56 mm, and the connector shell adds another
  1.75 mm. The port cutout is positioned by the ESP32, not by the board edge.
- **USB-C and the 4-pin cable exit opposite ends** - USB at -X, the cable at
  +X. Convenient: the two openings never compete for the same wall.

The tallest item is the mated connector, not the ESP32. `xh_mated_h` is now
measured at **11.6 mm** from `images/sensor_profile.jpg`. It does not include
wire bend radius past the plug - budget that separately at the cable exit.

## Fasteners

M2 passes the perfboard's corner holes; M2.5 does not. Mount through the
perfboard's four corners - the ESP32's own mounting holes are unused, since it
is soldered to the perfboard.

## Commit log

2026-08-03 create esp32 model
    [esp32.scad, esp32.stl, esp32_devkitv1.3mf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]
2026-08-03 add perfboard model
    [esp32.stl, params.scad, perfboard.scad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]
2026-08-03 add connector model and assembly model
    [assembly.scad, assembly.stl, connector.scad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]
2026-08-03 add sensor model
    [assembly.stl, esp32.stl, params.scad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]
2026-08-03 add enclosure plan
2026-08-03 add draft of main enclosure
    [assembly.scad, assembly.stl, enclosure_common.scad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]
2026-08-03 draft enclosures
    [enclosure_mcu_base.stl, enclosure_mcu_lid.stl, enclosure_pod_a.stl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]
2026-08-03 updates after fit gauge
    [enclosure_common.scad, enclosure_mcu.scad, enclosure_mcu_base.stl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]
2026-08-03 updated fitgauge
    [fitgauge.scad, fitgauge.stl, fitgauge_screws.stl]
2026-08-03 changes after second fitgauge
    [connector.scad, enclosure_mcu_base.stl, enclosure_mcu_lid.stl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]
2026-08-03 remove overhang in sensor pod
    [enclosure_mcu_base.stl, enclosure_mcu_lid.stl, enclosure_pod_a.stl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]
2026-08-04 sensor enclosure fit test passed
    [enclosure_mcu.scad, enclosure_mcu_base.stl, enclosure_mcu_lid.stl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]
2026-08-05 sensor enclosure validated
    [params.scad]
